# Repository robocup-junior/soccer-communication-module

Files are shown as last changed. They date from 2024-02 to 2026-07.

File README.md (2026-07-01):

# RCJ Soccer Communication Module

<p align="center">
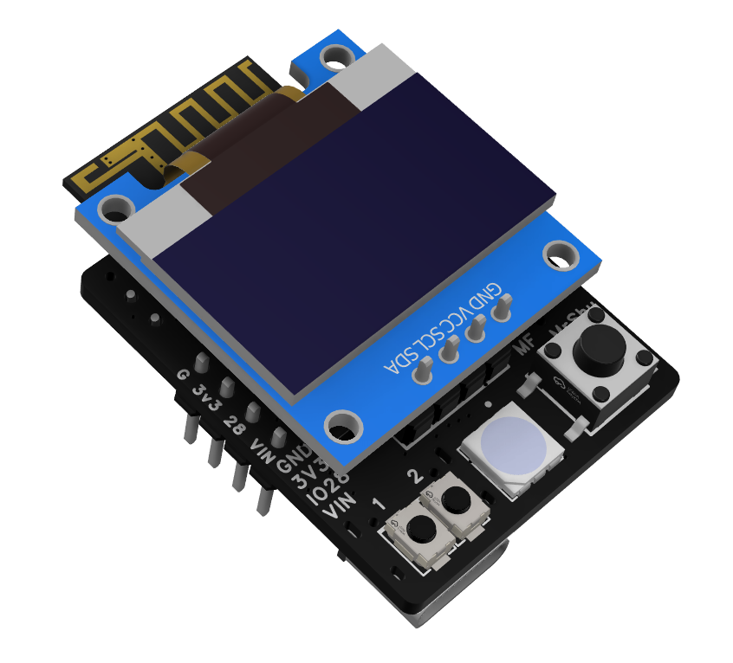
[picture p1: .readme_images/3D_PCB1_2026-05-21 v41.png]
RCJ Soccer communication module
  
</p>

A small referee-to-robot interface for **RoboCupJunior Soccer**. A referee controls the module over **Bluetooth Low Energy (BLE)** from the mobile app, and the module relays the live match state — **PLAY, STOP, penalty, half-time, game over** — to the robot or host controller over simple digital outputs, UART, or USB serial.

The current module (board **V7 / 2026**) is built around an **ESP32-C5** and includes an OLED display, three buttons, an RGB LED, a buzzer, a USB-C port for power & flashing, and an on-board **supercapacitor** backup. It does **not** count toward the robot weight limit.

> 📦 **Got an older 2024 board?** That one uses an ESP32-**C6** — see [Legacy 2024 (ESP32-C6) modules](#-legacy-2024-esp32-c6-modules) below.

---

## 🚀 Get started

**1. Install the referee app** — Android, free on Google Play:

**➡️ [RCJ Soccer app on Google Play](https://play.google.com/store/apps/details?id=com.robocup.rcj_soccer)**

**2. Flash the module** — easiest is the **web flasher**, nothing to install:

**➡️ [Web flasher](https://robocup-junior.github.io/soccer-communication-module/)** — connect the module over USB-C and flash straight from your browser.

> The web flasher uses the Web Serial API, so use **desktop Chrome or Edge**.

**3. Wire it to your robot** — power the module from the robot battery and read one start/stop signal (see [below](#-connecting-it-to-your-robot)).

---

## 📱 Using the app

The app connects to the module over BLE and drives the whole match. The interaction pattern:

- **Double-click** for actions — e.g. double-click a robot to start/stop it, or to issue a penalty.
- **Hold** for settings — e.g. hold a robot button for connection settings.
- **Start/stop** resets all timers and starts/stops all robots at once.
- **Score:** double-click a score to add a point; hold the score number for −1.

The app's source code lives in its own repository: **[robocup-junior/soccer-referee-app](https://github.com/robocup-junior/soccer-referee-app)**.

---

## 🔌 Connecting it to your robot

### Read the start/stop signal (pick one method)

The robot must respond to the start/stop signal for the entire game. Use **one** of the following methods and react whenever the state changes:

| Method | Pin | PLAY / GO | STOP |
|---|---|---|---|
| **Output pin** | `OUT1` or `OUT2` | **3.3 V** (HIGH) | **0 V** (LOW) |
| **UART** | `TX0` (UART0 on the U3 header) | sends `PLAY` | sends `STOP` |
| **USB serial** | USB-C | sends `PLAY` | sends `STOP` |

Both outputs carry the same 3.3 V logic-level signal. For 5 V robot inputs, add a level shifter before the robot. Always share **GND** with the robot controller — never connect VIN to a robot GPIO or to the 3.3 V pin.

For a Raspberry Pi or another USB host, connect the module's USB-C port to the host's USB-A port. The ESP32-C5 enumerates as a serial device, typically `/dev/ttyACM0`, and prints one line (`PLAY` or `STOP`) whenever the referee app changes the match state.

On Linux, you can check the USB serial output with:

```sh
stty -F /dev/ttyACM0 115200 raw -echo
cat /dev/ttyACM0
```

### Power it

Power the module **directly from the robot battery** so it stays alive for the whole match — even when the robot is switched off or removed from the field — to keep a stable BLE connection.

- **Battery:** connect **VIN** to battery **+** and **GND** to battery **−** (no switch in between). VIN accepts **4.5 V – 50 V** (the on-board buck regulator is rated higher, but RoboCupJunior rules cap robot voltage at 50 V).
- **USB-C:** the module can also run from USB-C (VBUS).
- **Regulated 3.3 V:** you may instead feed **3.3 V** to the 3V3 pin. If you do, design the supply to cover a short **startup demand of ~0.5 A at 3.3 V (≈1.65 W)**; steady-state draw is far lower.

### Supercapacitor backup

The back-side **supercapacitor** rides through short voltage dips during play (e.g. a battery sag). Switch the **supercapacitor switch ON before the match**, and **OFF when the module is not in use** so it doesn't stay charged in storage.

### Mounting

Mount the module where the **display stays visible** and the connector is **easy to reach** — typically on top of the robot via a hub, either on your own PCB or on protoboard/breadboard. We can also provide a limited number of **hub boards** you can permanently attach to your robot ([hub photo](./.readme_images/hub_image.png?raw=true)).

---

## ⏱️ During the match

### Penalties (fast & quiet)

To penalize a robot, **double-press the large button** on the module. The module sends a penalty request to the referee app, so the right robot is identified and the penalty timer starts — no shouting robot designators across the field. The firmware detects the double-press and sends the request **only while the robot is in the PLAY state**.

### Putting robots back in

The OLED shows a **countdown** for the duration of a robot's penalty. Teams may return robots to play, per the rules, once the penalty time is up on the display.

---

## 🤖 Robot-to-robot communication

Direct robot-to-robot communication is **planned for a future firmware release**. The current firmware relays the referee's match state (start/stop, penalty, half-time, game over) only — via the output pins or UART described above.

> The old 2024 board's channel-select `A0`/`A1` pins and the `LOGV` UART-level pin are **not** present on this hardware.

---

## 🛠️ Firmware & flashing (details)

For most users the [web flasher](https://robocup-junior.github.io/soccer-communication-module/) is all you need. Under the hood:

The firmware is an **ESP-IDF** project (Arduino runs as an IDF component). Releases are built automatically from Git tags matching `fw-*` or `v*` — pushing a tag makes GitHub Actions build the ESP32-C5 firmware, publish a GitHub Release with the `.bin` files, and deploy the latest web flasher to GitHub Pages:

```sh
git tag fw-v0.97
git push origin fw-v0.97
```

The release includes a single **merged image** (bootloader + partition table + app) plus the individual bins for `idf.py`/esptool users.

---

## 🧩 Legacy 2024 (ESP32-C6) modules

The older 2024 board uses an **ESP32-C6** (no USB-C connector) instead of the current ESP32-C5. It is still supported with a final, maintained firmware on the **[`legacy/esp32-c6`](https://github.com/robocup-junior/soccer-communication-module/tree/legacy/esp32-c6)** branch. Those builds are published as **GitHub Release assets** (tags `legacy-c6-*`); there is no web flasher for them.

**Flashing (native USB — recommended):** the C6's USB D+/D− are broken out on the programming header. Wire them to a USB port (the module enumerates as a serial device), then flash the merged image with full erase:

```sh
esptool --chip esp32c6 -p <PORT> write_flash --erase-all 0x0 rcj_comm_module-<ver>-merged.bin
```

A UART path also exists via the level-shifted RX/TX header pins, but it needs the `LOGV` pin powered at 3.3 V and manual download-mode entry (hold IO9/BOOT low, pulse EN), so native USB is easier. Either path can use the special flashing jig PCB.

---

## ❓ Not working?

Check the [open issues](https://github.com/robocup-junior/soccer-communication-module/issues) first and — if nobody has posted yours yet — open a [new GitHub issue](https://github.com/robocup-junior/soccer-communication-module/issues/new), post on [the forum](https://junior.forum.robocup.org/c/robocupjunior-soccer/5), or ask on the [RoboCupJunior Discord](https://discord.gg/45pxMQY4nJ).

## 🙌 Could use some help with

- An adapter hub for EV3 / SPIKE
- More component libraries (footprint / schematic / 3D) for Altium, Eagle, KiCad, EasyEDA, OrcaCAD, …
- Reporting errors & testing

## 🔭 Currently working on

- Robot-to-robot communication
- RGB LED & buzzer feedback

## 🏆 Hall of fame

- App by Mato Faltus
- Altium lib by Youssef Shaalan

---

## 📄 Quick connection guide

A printable one-page (A5) summary of the pinout, signals, power, and wiring:

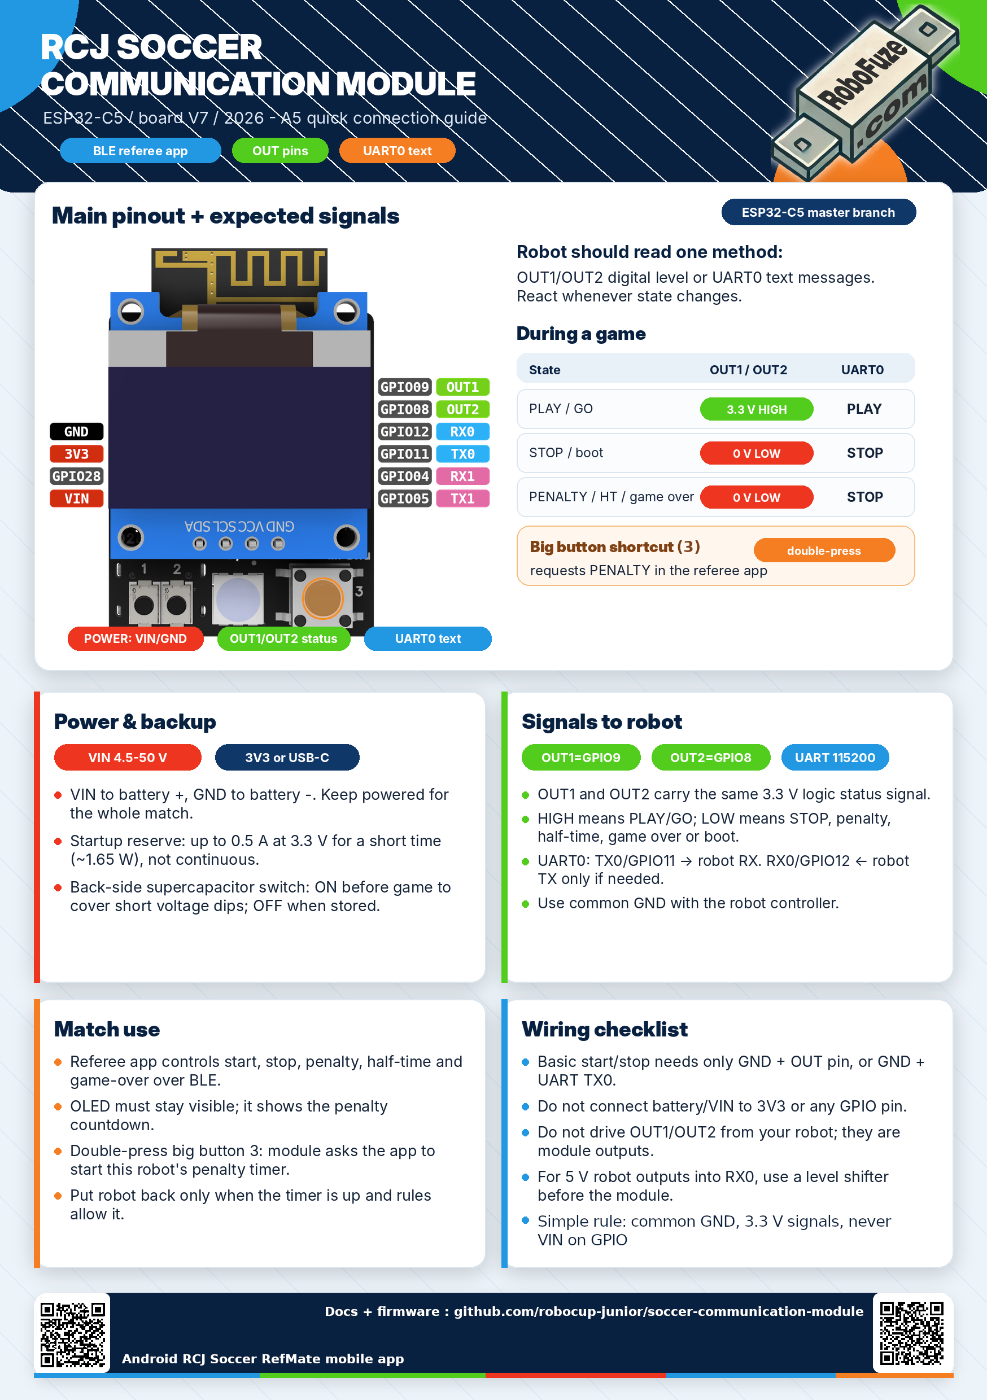
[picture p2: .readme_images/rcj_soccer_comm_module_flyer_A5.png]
RCJ Soccer Communication Module — quick connection guide


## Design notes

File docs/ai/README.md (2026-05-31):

# AI Agent Documentation — RCJ Soccer Communication Module

This folder is the **entry point for AI agents** (and humans) who need to understand
and later safely modify this project. It was written by inspecting the working tree,
source code, git history, build/release tooling, the web flasher, and the new-hardware
3D render images. Where something could not be proven from the repository it is marked
as **inferred**, **unknown**, or **to verify from schematic**.

> ℹ️ The public top-level `README.md` was rewritten on 2026-05-31 to describe the **current
> V7/2026 (ESP32-C5)** hardware (USB-C, RGB LED, buzzer, 3 buttons, supercap; no more
> A0/A1/LOGV pins). The old `RCJ 2024 communication modules.pdf` and 2024 design files were
> removed from `master` (they remain in git history / on `legacy/esp32-c6`). This `docs/ai/`
> folder and the live source code remain the most detailed source of truth.

> 📌 **Also read [`firmware/RCj_comm_module/AI_HANDOFF.md`](../../firmware/RCj_comm_module/AI_HANDOFF.md).**
> It is the handoff note written by the previous single-agent session that did the BLE
> latency, release-workflow, and web-flasher work. It has been cross-checked against the
> code and is **accurate and consistent with this docs set**; it adds the *rationale*
> behind several decisions (the since-revised 20 s BLE timeout, MAC-in-name for iPhones, NOTIFY
> over INDICATE, the manual USB RTS reset) and the **mobile-app expectations**. Key user
> rule from it: **never `git push` unless the user explicitly asks in that turn.**

## Project summary

A small board that mounts on a RoboCupJunior Soccer robot. It connects over **BLE** to a
mobile referee/control app (Nordic UART Service profile). The app sends match commands
(`PLAY`, `STOP`, penalty/damage, halftime, game over, score, name). The firmware drives
two digital **output pins** (`OUT1`/`OUT2`) that the robot reads to start/stop, and shows
the current match state on a 128×64 **SSD1306 OLED** (including a QR code of the BLE MAC
while waiting for a connection).

## Current status (as of fw v0.97)

- Firmware version **0.97** (`definitions.h`: `FW_VERSION_MAJOR=0`, `FW_VERSION_MINOR=97`),
  not yet tagged/released (latest released tag is `fw-v0.96`). v0.97 (working tree) bundles:
  `BLE_CONN_TIMEOUT` 20 s → 3 s (faster reconnect + faster fail-safe stop), and a clean
  release UART (bootloader/IDF logs OFF, console on UART0) with a `sdkconfig.debug` overlay
  for USB-C logging during development.
- Target chip: **ESP32-C5**, ESP-IDF **v5.5.4**, `espressif/arduino-esp32` `^3.3.0`, **NimBLE**.
- Runs on the new ESP32-C5 hardware in **legacy-compatibility mode**: same behavior as the
  old module, only with remapped pins. UART/`Serial` is still used (debug prints + legacy).
- New hardware (silkscreen **"V7 2026"**, branding "robofuze") adds RGB LED, buzzer,
  supercapacitor backup, three buttons, ON/OFF switch, and USB-C direct programming.
  **None of the RGB LED / buzzer / 3rd-button / supercap features are implemented in
  firmware yet.**
- Release/flashing is automated: Git tag → GitHub Actions → GitHub Release + GitHub Pages
  web flasher (Web Serial / esptool-js, ESP32-C5 USB reset path).

## Where to start reading

| Order | Document | Topic |
|---|---|---|
| 1 | [00_project_overview.md](00_project_overview.md) | What the module does, old vs new HW |
| 2 | [01_repository_map.md](01_repository_map.md) | Folder/file layout, source vs generated |
| 3 | [02_firmware_architecture.md](02_firmware_architecture.md) | Modules, main loop, RTOS queue |
| 4 | [03_ble_protocol.md](03_ble_protocol.md) | UUIDs, message IDs, payloads, direction |
| 5 | [04_state_machine.md](04_state_machine.md) | States, transitions, output behavior |
| 6 | [05_hardware_mapping.md](05_hardware_mapping.md) | Pin map (C5 + legacy C6), to-verify |
| 7 | [06_display_and_user_feedback.md](06_display_and_user_feedback.md) | Screens, proposed LED/buzzer |
| 8 | [07_build_release_and_flasher.md](07_build_release_and_flasher.md) | Build, CI, web flasher |
| 9 | [08_mobile_app_interaction.md](08_mobile_app_interaction.md) | App behavior, command mapping |
| 10 | [09_known_issues_and_open_questions.md](09_known_issues_and_open_questions.md) | Risks, TODOs, unknowns |
| 11 | [10_future_change_plan.md](10_future_change_plan.md) | Staged plan for new HW features |
| 12 | [11_legacy_c6_firmware.md](11_legacy_c6_firmware.md) | Final legacy ESP32-C6 firmware: git layout, build, flashing, release plan |

## Most important source files

| File | Role |
|---|---|
| `firmware/RCj_comm_module/RCj_comm_module.ino` | Arduino-IDE entry point (`setup`/`loop`) |
| `firmware/RCj_comm_module/main/app_main.cpp` | ESP-IDF entry point (`app_main`), mirrors the `.ino` |
| `firmware/RCj_comm_module/definitions.h` | Versions, BLE/UART constants, **GPIO pin map** |
| `firmware/RCj_comm_module/ble.cpp` / `.h` | BLE server, UUIDs, RX/TX characteristics, callbacks |
| `firmware/RCj_comm_module/ble_processing.cpp` / `.h` | Message IDs enum, queue, command dispatch |
| `firmware/RCj_comm_module/state_machine.cpp` / `.h` | States, output pin control, timers |
| `firmware/RCj_comm_module/display.cpp` / `.h` | OLED screen rendering |
| `firmware/RCj_comm_module/functions.cpp` / `.h` | MAC, score/indicator state, GPIO init, button logic |
| `tools/prepare_firmware_release.py` | Builds release artifacts + flasher manifest |
| `.github/workflows/firmware-release.yml` | CI build/release/Pages deploy |
| `web/flasher/app.js` | Web Serial flasher logic |

## Current limitations / cautions for agents

- **Do not make functional firmware changes** until the new schematic is available and the
  pin map in `05_hardware_mapping.md` is verified.
- The `.ino` and `main/app_main.cpp` define **two parallel entry points** that must be kept
  in sync (see [02](02_firmware_architecture.md)). The CI build uses the ESP-IDF path
  (`main/`), not the `.ino`.
- `BUTTON_GPIO` is shared between the disconnect (long-press) and penalty (double-press)
  logic — changing one affects the other.
- `stm_init()` sets a timer to `660000 ms` with a `// DOTO why ist here this? WTF` comment —
  origin/purpose unconfirmed (see [04](04_state_machine.md)).
- The **V7/2026 schematic is in the repo**: `pcb_schematic/SCH_Schematic1_2026-05-31.pdf`,
  with a pin-by-pin reference at `docs/ai/ESP32C5_RCJ_modul_hardware_reference.md`
  (**authoritative hardware source**). The firmware pin map matches it for all implemented
  peripherals. The older 2024 (C6) schematic/libraries were removed from `master` on
  2026-05-31 — find them in git history or on the `legacy/esp32-c6` branch.
</content>
</invoke>

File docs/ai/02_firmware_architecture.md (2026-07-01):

# 02 — Firmware Architecture

## Module breakdown

| Module | Files | Responsibility |
|---|---|---|
| Entry point (Arduino) | `RCj_comm_module.ino` | `setup()` / `loop()` for Arduino-IDE builds |
| Entry point (ESP-IDF) | `main/app_main.cpp` | `app_main()` → `initArduino()` + setup/loop, for CI/IDF builds |
| Definitions | `definitions.h` | Versions, BLE/UART constants, GPIO pin map |
| BLE transport | `ble.cpp` / `ble.h` | NimBLE server, NUS UUIDs, RX/TX characteristics, callbacks, send/disconnect |
| BLE processing | `ble_processing.cpp` / `ble_processing.h` | `ble_msg_t`, `ble_msg_id` enum, RTOS queue, command dispatch |
| State machine | `state_machine.cpp` / `state_machine.h` | `stm_states`, output-pin control, timer |
| Display | `display.cpp` / `display.h` | SSD1306 rendering per state |
| Functions/util | `functions.cpp` / `functions.h` | MAC string, score/indicator globals, GPIO init, button handling |
| Assets | `fonts.h`, `images.h` | OLED fonts and boot logo (`RC_logo`) |

## Two parallel entry points (IMPORTANT)

There are **two** entry points that do the same four things in the same order:

`RCj_comm_module.ino` (Arduino IDE):
```c
void setup() { Serial.begin(UART_SPEED); display_init(); module_init_gpios(); stm_init(); ble_start_server(); }
void loop()  { ble_msg_processing(); stm_update(); check_disconnect_button(); check_penalty_button(); }
```

`main/app_main.cpp` (ESP-IDF — what CI actually builds):
```c
static void module_setup() { Serial.begin(UART_SPEED); display_init(); module_init_gpios(); stm_init(); ble_start_server(); }
static void module_loop()  { ble_msg_processing(); stm_update(); check_disconnect_button(); check_penalty_button(); }
extern "C" void app_main(void) { initArduino(); module_setup(); while (true) { module_loop(); delay(1); } }
```

> **Maintenance hazard:** any change to setup/loop logic must be mirrored in **both** files,
> or the Arduino-IDE and ESP-IDF builds will diverge. The release pipeline builds the
> **ESP-IDF** path (`main/app_main.cpp`); the `.ino` is for local Arduino-IDE use.

## Initialization sequence

1. `Serial.begin(UART_SPEED)` — `UART_SPEED = 115200`. Used for debug prints only.
2. `display_init()` — `SSD1306 display(0x3c, I2C_SDA_GPIO, I2C_SCL_GPIO)`, `display.init()`.
3. `module_init_gpios()` — `OUTPUT1_GPIO`/`OUTPUT2_GPIO` as `OUTPUT`; `BUTTON_GPIO`/`BUTTON2_GPIO` as `INPUT` (no explicit pull configured — see hardware doc).
4. `stm_init()` — current state stays `STM_INIT`; sets timer to `660000 ms` (see below / [04](04_state_machine.md)).
5. `ble_start_server()` — creates the message queue, BLE device, server, service, RX/TX characteristics, and starts advertising.

## Main loop behavior

`loop()` runs continuously (in IDF: `while(true) { ...; delay(1); }`). Each iteration:

1. **`ble_msg_processing()`** — pops at most **one** message from the queue (`xQueueReceive`
   with timeout `0`) and dispatches it. Non-blocking; returns immediately if empty.
2. **`stm_update()`** — runs the current state's handler and, on a state change, updates
   the output pins.
3. **`check_disconnect_button()`** — long-press (`DISCONNECT_HOLD_TIME = 5000 ms`) on
   `BUTTON_GPIO` triggers `ble_disconnect()`.
4. **`check_penalty_button()`** — double-press on `BUTTON_GPIO` **or** `BUTTON2_GPIO`
   triggers `ble_msg_procesing_ask_for_penalty()`.

There is **no explicit task split**: everything runs in the single `app_main`/loop thread.
BLE callbacks run in the NimBLE host context and only enqueue work, keeping the ISR/callback
path short.

## Concurrency / FreeRTOS

The only cross-context shared structure is the BLE message queue.

- Created in `ble_msg_processing_init()`:
  `xQueueCreate(BLE_QUEUE_MAX_SIZE /*16*/, sizeof(ble_msg_t))`.
- **Producer:** `ble.cpp` `MyCallbacks::onWrite()` → `queue_ble_msg()` (BLE host context).
- **Consumer:** `ble_processing.cpp` `ble_msg_processing()` (main loop).

`queue_ble_msg()` (added in `ca23261`) implements an **overwrite-on-full** policy: if the
queue is full it drops the **oldest** message (`xQueueReceive`) and retries the send, so the
newest referee command is never lost to a backlog. Both `ble.cpp` and `ble_processing.cpp`
hold their own `static QueueHandle_t ble_msg_queue`; `ble.cpp` fetches the handle via
`ble_msg_proccesing_get_queue()` during `ble_start_server()`.

Other shared globals (`current_state`, `robot_play`, `timer_stop`, `module_indicator`,
`my_score`, `opponent_score`, `device_connected`) are accessed without locks. In practice
state mutations happen either in the loop or in BLE callbacks; `stm_set_state()` is called
from both `ble_processing` (loop) and `MyServerCallbacks::onDisconnect` (BLE context) —
a benign data race on `current_state`/`state_changed` that has not caused observed issues
but is worth noting for any future hardening.

## Important global state

| Variable | File | Meaning |
|---|---|---|
| `current_state` | `state_machine.cpp` | Active `stm_states` value |
| `state_changed` | `state_machine.cpp` | One-shot flag: forces re-render + output update next `stm_update()` |
| `robot_play` | `state_machine.cpp` | Drives `OUTPUT1/2` HIGH/LOW |
| `timer_stop` | `state_machine.cpp` | `millis()` deadline for penalty/halftime countdown |
| `device_connected` | `ble.cpp` | BLE connection state |
| `module_indicator` | `functions.cpp` | 2-char team/robot label (default `"--"`) |
| `my_score`, `opponent_score` | `functions.cpp` | Scoreboard values |

## Legacy UART / Serial behavior

- `Serial.begin(115200)` is called at startup.
- `update_output_satet()` in `state_machine.cpp` prints `"PLAY"` / `"STOP"` through
  `serial_status_println()` on every output change. That helper mirrors each line to
  Arduino `Serial` (UART0 on U3) and the ESP32-C5 USB Serial/JTAG port (USB-C, typically
  `/dev/ttyACM*` on Linux). **These are the only active serial status prints in the firmware**
  and double as status channels for robots or Raspberry Pi hosts that read serial instead
  of the OUT pins.
- All other debug prints are **already commented out**: `ble.cpp:45,64,147,149`,
  `ble_processing.cpp:71`, `functions.cpp:107,121`. (Verified 2026-05-31.) The vendored
  `libraries/**/examples/*.ino` prints are not compiled; the OLED lib's `"[deprecated]"`
  prints live in `drawLogBuffer()`/`setLogBuffer()`, which the firmware never calls.
- **No robot-to-robot UART protocol** (RX/TX framing, channel select) exists in the current
  firmware, despite the public README describing RX/TX/LOGV/A0/A1 on the 2024 board.

### UART output cleanliness (for robots that read serial, not pins)

Verified against the generated build config (`build/config/sdkconfig.h`, 2026-05-31):

1. **✅ `Serial` routes to UART0 (the U3 `TX_OUT` the robot reads).** `ARDUINO_USB_CDC_ON_BOOT`
   is **not** defined, so `Serial` = `HardwareSerial(0)` = UART0; and `CONFIG_ESP_CONSOLE_UART_DEFAULT=y`
   with `CONFIG_ESP_CONSOLE_UART_NUM=0`. So `PLAY`/`STOP` do reach the robot's UART pins.
   (`ARDUHAL` log level is already ERROR-only, so the Arduino layer adds no chatter.)
2. **✅ Boot log silenced for release (fixed 2026-05-31).** `sdkconfig.defaults` now sets
   `CONFIG_BOOTLOADER_LOG_LEVEL_NONE=y`, `CONFIG_LOG_DEFAULT_LEVEL_NONE=y`,
   `CONFIG_ARDUHAL_LOG_DEFAULT_LEVEL_NONE=y`, and pins the console to UART
   (`CONFIG_ESP_CONSOLE_UART_DEFAULT=y`). So a release build's UART0 line carries only the
   Arduino `Serial` output (`PLAY`/`STOP`) — those are plain UART writes, not log macros, so
   they survive. The ROM's very first line (`ESP-ROM:…`, reset cause) is emitted before
   sdkconfig applies and can only be removed via eFuse — **accepted as-is for now**
   (maintainer decision 2026-05-31): it's one short burst once at power-on, not during play.

### Build flavors: release (UART, clean) vs debug (USB, verbose)

| | Release (default) | Debug overlay |
|---|---|---|
| Config | `sdkconfig.defaults` only | `sdkconfig.defaults` + `sdkconfig.debug` |
| IDF/bootloader logs | OFF (`*_LOG_LEVEL_NONE`) | INFO |
| IDF console route | UART0 | **USB-C** (`CONFIG_ESP_CONSOLE_USB_SERIAL_JTAG`) |
| Arduino `Serial` (`PLAY`/`STOP`) | UART0; mirrored to USB-C by `serial_status` | UART0; mirrored to USB-C by `serial_status` |
| Built by | CI on every tag | local dev only |

Debug build command:
`idf.py -D SDKCONFIG_DEFAULTS="sdkconfig.defaults;sdkconfig.debug" build flash monitor`
(later defaults file wins on conflicting choices). This keeps the UART0 line free for the
robot while a developer watches logs over USB-C. `Serial`'s `PLAY`/`STOP` stays on UART0 in
both flavors, and `serial_status` mirrors those same lines to USB Serial/JTAG for USB hosts.

## Source files reviewed

`RCj_comm_module.ino`, `main/app_main.cpp`, `definitions.h`, `ble.cpp/.h`,
`ble_processing.cpp/.h`, `state_machine.cpp/.h`, `display.cpp/.h`, `functions.cpp/.h`,
git commit `ca23261`.

## Open questions

- Should the loop adopt a dedicated FreeRTOS task / explicit synchronization for state?
- Is the `.ino` still maintained, or should it be retired in favor of the IDF `main/` path?
</content>

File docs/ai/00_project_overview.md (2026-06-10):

# 00 — Project Overview

## What this module is

The RCJ Soccer Communication Module is a small mountable board for RoboCupJunior Soccer
robots. It provides a referee-controlled start/stop (and penalty/halftime/game-over)
channel between a mobile referee app and the robot, plus a status display. The board does
not count toward the robot weight limit (per public `README.md`).

Core responsibilities:

1. Advertise and accept a **BLE** connection from the mobile referee/control app.
2. Receive match commands over BLE and react.
3. Drive two digital **output pins** (`OUT1`, `OUT2`) that the robot continuously reads:
   **3.3 V = GO/PLAY, 0 V = STOP** (public README confirms the electrical meaning).
4. Show the current state on a 128×64 OLED, including a QR code of the BLE MAC address
   while waiting for a connection, and a penalty/halftime countdown.
5. Offer local buttons for disconnect and a self-penalty request back to the app.

## Match-level behavior

| Phase | What happens |
|---|---|
| Power-on | Boot/logo screen with firmware version, then "Wait for connection" screen with QR + MAC |
| Referee connects (app) | BLE link established; app drives state |
| `PLAY` | Outputs go HIGH; robot plays; display shows team indicator + score |
| `STOP` | Outputs go LOW; robot stops |
| Penalty / damage | Outputs LOW; display shows a countdown; robot returns when timer hits 0 |
| Halftime | Outputs LOW; display shows a countdown |
| Game over | Outputs LOW; display shows final score + indicator |
| Self-penalty request | Local double-press of the button asks the app for a penalty (only while playing) |
| BLE disconnect | Returns to "Wait for connection" state |

The module is expected to be **powered at all times during the match** (even off-field) to
keep the BLE link stable (public README). The new hardware adds a **supercapacitor** so the
module can survive a short power drop without losing the connection/state (maintainer note).

## Control flow: app → BLE → module → robot

```
Mobile referee app
      │  BLE write (Nordic UART RX characteristic)
      ▼
ble.cpp  MyCallbacks::onWrite()  ── parses [msg_id][data...] ──► FreeRTOS queue
      │
      ▼
ble_processing.cpp  ble_msg_processing()  ── dispatch by msg_id ──►
      ├─ stm_set_state(STM_PLAY/STOP/DAMAGE/HALF_TIME/GAME_OVER)
      ├─ module_set_indicator() / module_set_my_score() / module_set_opponent_score()
      └─ ble_send_msg() for PING echo / FW_VERSION reply
      │
      ▼
state_machine.cpp  stm_update()
      ├─ update_output_satet(): OUTPUT1/OUTPUT2 GPIO HIGH (play) or LOW (stop)
      └─ display_screen_*(): render current screen
      │
      ▼
Robot reads OUT1/OUT2 (3.3 V = GO, 0 V = STOP)
```

The reverse direction (module → app) carries: `BLE_MSG_PING` echo, `BLE_MSG_FW_VERSION`
reply, `BLE_MSG_ASK_FOR_PENALTY` (self-penalty request), and `BLE_MSG_DISCONNECT`
notification before disconnecting. See [03_ble_protocol.md](03_ble_protocol.md).

## Old hardware vs new ESP32-C5 hardware

| Aspect | Old 2024 module | New module (silkscreen "V7 2026", "robofuze") |
|---|---|---|
| MCU | ESP32-**C6** (legacy pin block still commented in `definitions.h`) | ESP32-**C5** (PCB-antenna module) |
| Programming | External (per old docs) | **USB-C** direct, onboard |
| Power | BAT+ / GND (5.3–25 V) or 3V3 | Same + **supercapacitor backup**, ON/OFF slide switch |
| Inputs | Buttons (2 used in firmware) | **3 buttons** (silk "1", "2", "3"/"MF") |
| Feedback | OLED display | OLED + **RGB LED** + **buzzer** |
| Robot I/O | RX/TX UART, A0/A1 channels, LOGV, OUT1/OUT2 | OUT1/OUT2 confirmed in firmware; UART/RX-TX status **to verify** |

> The old/UART-based robot-to-robot communication (RX, TX, LOGV, A0/A1 channels) is
> described only in the public README/PDF. The **current firmware does not implement any
> RX/TX robot-to-robot UART protocol** — `Serial` is used at 115200 baud only for debug
> prints (`"PLAY"`/`"STOP"`) and as a side effect of `Serial.begin()`. The V7 schematic
> shows the board keeps UART headers — UART0 (RX0/TX0, primary/flashing) and UART1
> (RX1=IO4, TX1=IO5, secondary to robot) on the U3 connector — but the legacy LOGV/A0/A1
> channel scheme is gone. See [05_hardware_mapping.md](05_hardware_mapping.md).

## Current compatibility mode

The maintainer describes the firmware as running on ESP32-C5 in a **limited compatibility
mode**: it behaves like the old hardware with changed pins. Concretely, the only behavioral
delta vs the old code path that is implemented is:

- Pin remap to ESP32-C5 (`definitions.h`, C6 block commented out).
- BLE switched to NimBLE with tuned connection parameters and write-without-response
  (commit `ca23261` "Improve BLE command latency and resilience").
- A self-penalty request via double-press (commit `e423b0d`).

## Planned hardware features (NOT implemented yet)

These are on the board (confirmed in the V7 schematic) but have **no firmware support yet**;
pins are now known (see [05_hardware_mapping.md](05_hardware_mapping.md)):

- **RGB LED** — discrete common-cathode, active-high: R=IO27, G=IO24, B=IO23 (470 Ω each).
  ⚠️ **R/G are swapped on the real board** (footprint bug): IO27 lights **green**, IO24
  lights **red** (blue is fine). See [05](05_hardware_mapping.md) / the hardware reference.
- **Buzzer** — passive 2.7 kHz via NPN Q1 on **IO26** (pin 27); needs PWM tone.
- **Supercapacitor backup** — 15 F (C1); hardware ride-through, no firmware action required.
- **Third button** B3 = **IO6** (SW2) — firmware currently wires only two buttons
  (`BUTTON_GPIO`=IO10/B1, `BUTTON2_GPIO`=IO7/B2).
- **Slide power switch** (U6) — enables/disables supercap backup; firmware-invisible.

Do not implement these until the schematic confirms pins. See
[10_future_change_plan.md](10_future_change_plan.md).

## Source files reviewed

`README.md`, `firmware/RCj_comm_module/*` (all `.ino/.cpp/.h`), `main/app_main.cpp`,
`.readme_images/3D_PCB1_2026-05-21 v4*.png`, git history (`7f9fb81`, `ca23261`, `e423b0d`).

## Open questions

- Does the new board still expose a robot-to-robot UART (RX/TX/LOGV/A0/A1) header?
- Must old-module BLE compatibility be preserved bit-for-bit with the existing app?
- Is the supercapacitor purely hardware ride-through, or should firmware detect a power dip?
</content>

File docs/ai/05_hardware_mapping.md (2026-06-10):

# 05 — Hardware Mapping

The V7/2026 schematic is now in the repo and the pin map is **confirmed**:
- Schematic: `pcb_schematic/SCH_Schematic1_2026-05-31.pdf` (EasyEDA "ESP32C5_RCJ_modul",
  Board1 / Schematic1, V1.0, MCU **ESP32-C5-WROOM-1** — schematic label `-N16R4`, but the
  fitted flash reads **8 MB** via JEDEC (build is configured for 8 MB; see the hardware
  reference's "Microcontroller — U1" note) / 4 MB PSRAM).
- Authoritative pin reference (maintainer-authored, read pin-by-pin from U1):
  [`ESP32C5_RCJ_modul_hardware_reference.md`](ESP32C5_RCJ_modul_hardware_reference.md).

> ✅ **The firmware (`definitions.h`) matches the V7 hardware for every implemented
> peripheral** (I2C, the two wired buttons, the two robot outputs). The RGB LED, buzzer,
> third button, and UART1 exist on the board but are **not yet used by firmware** — their
> confirmed pins are listed below.

## Current firmware pin map — ESP32-C5 (active)

```c
// ESP-C5  (definitions.h)
#define I2C_SDA_GPIO    2     // OLED SDA
#define I2C_SCL_GPIO    3     // OLED SCL
#define BUTTON_GPIO     10    // primary button (disconnect long-press + penalty double-press)
#define BUTTON2_GPIO     7    // secondary button (penalty double-press)
#define OUTPUT1_GPIO     9    // robot start/stop OUT1 (HIGH=play, LOW=stop)
#define OUTPUT2_GPIO     8    // robot start/stop OUT2 (mirrors OUT1)
```

| Function | C5 GPIO | Direction | V7 net / part | Notes |
|---|---|---|---|---|
| I2C SDA (OLED) | 2 | — | SDA, H2 hdr | `SSD1306(0x3c, SDA, SCL)` ✅ matches HW |
| I2C SCL (OLED) | 3 | — | SCL, H2 hdr | I2C addr `0x3c` ✅ matches HW |
| OUT1 | 9 | output | OUT1, U3 hdr | robot GO/STOP signal ✅ matches HW (IO9) |
| OUT2 | 8 | output | OUT2, U3 hdr | duplicate of OUT1 ✅ matches HW (IO8) |
| BUTTON | 10 | input | **B1 = SW5** | disconnect (5 s hold) **and** penalty (double-press); SW5 is the 4-pin slide/toggle "power/mode" switch |
| BUTTON2 | 7 | input | **B2 = SW1** | penalty (double-press); SW1 momentary tactile |

> Note: firmware `BUTTON_GPIO` (10) is hardware **B1/SW5** (the 4-pin slide/toggle switch),
> and `BUTTON2_GPIO` (7) is **B2/SW1**. The third button **B3/SW2 = IO6** is not wired in
> firmware. Hardware provides 10 kΩ pull-ups (R4/R5/R6) on all three, so the buttons are
> active-low as the firmware assumes.

## Legacy pin map — ESP32-C6 (commented out, retained for reference)

```c
// ESP-C6  (commented in definitions.h)
// I2C_SDA_GPIO    6
// I2C_SCL_GPIO    7
// BUTTON_GPIO     18
// BUTTON2_GPIO     9
// OUTPUT1_GPIO    20
// OUTPUT2_GPIO    19
```

These are kept as comments from the previous (C6) hardware revision. They are **not**
compiled. Useful only if a C6 board must be reflashed.

## Display / I2C

- Driver: ThingPulse SSD1306 (`libraries/ESP8266_and_ESP32_OLED_driver_for_SSD1306_displays`).
- Instance: `static SSD1306 display(0x3c, I2C_SDA_GPIO, I2C_SCL_GPIO)` in `display.cpp`.
- Resolution assumed 128×64 (boot draws `drawXbm(0,0,128,64,RC_logo)`).
- The new board exposes a 4-pin OLED header silk-labeled **`GND VCC SCL SDA`** (visible in
  the front render) — consistent with an external/standard SSD1306 module.

## Button handling (current behavior)

`functions.cpp`:
- `module_init_gpios()` sets `BUTTON_GPIO` and `BUTTON2_GPIO` as `INPUT`
  (no `INPUT_PULLUP` in firmware — OK because the board has **external 10 kΩ pull-ups**
  R4/R5/R6 to 3.3 V; confirmed in the schematic).
- Buttons are **active-low**: pressed reads `LOW` (`digitalRead(...) == LOW`,
  and penalty logic uses `!digitalRead(...)`).
- **`check_disconnect_button()`**: holding `BUTTON_GPIO` LOW for `DISCONNECT_HOLD_TIME`
  (5000 ms) calls `ble_disconnect()`.
- **`check_penalty_button()`**: a debounced (`DEBOUNCE_DELAY` 50 ms) **double-press**
  (within `DOUBLE_PRESS_MAX_DELAY` 1000 ms) of `BUTTON_GPIO` **OR** `BUTTON2_GPIO` calls
  `ble_msg_procesing_ask_for_penalty()` (sends `BLE_MSG_ASK_FOR_PENALTY`, only while
  `STM_PLAY`).

> **Shared-pin caution:** `BUTTON_GPIO` participates in both the disconnect long-press and
> the penalty double-press logic. A long hold could also register press edges in the penalty
> detector. Keep this in mind when redefining button roles for the 3-button board.

## UART / serial

- `UART_SPEED = 115200`. `Serial.begin()` at boot; used for `"PLAY"`/`"STOP"` debug prints.
- The V7 board exposes **two UARTs** on the U3 6-pin header (2541WV-06P):
  - **UART0** — `RX0`/`TX0` (net `RX_OUT`/`TX_OUT`, U3 pins 3–4). Primary serial, also the
    flashing/boot console.
  - **UART1** — `RX1 = IO4`, `TX1 = IO5` (U3 pins 5–6). Secondary serial to the robot.
- The 2024 README's RX/TX/LOGV/A0/A1 "channel" scheme is **not** present; the V7 board has
  plain UART0/UART1 instead. Firmware does **not** use UART1 yet.

## New V7/2026 hardware — CONFIRMED from schematic (NOT yet in firmware)

Pins below are from `ESP32C5_RCJ_modul_hardware_reference.md` (read pin-by-pin from U1) and
`pcb_schematic/SCH_Schematic1_2026-05-31.pdf`. Components seen on the 3D renders
(`.readme_images/3D_PCB1_2026-05-21 v4*.png`, silk "V7 2026", branding "robofuze").

| Feature | GPIO / part | Active level / drive | Firmware status |
|---|---|---|---|
| RGB LED Red | **IO27** via R9 470 Ω — ⚠️ **lights GREEN** (R/G footprint swap) | active **high** | not implemented |
| RGB LED Green | **IO24** via R8 470 Ω — ⚠️ **lights RED** (R/G footprint swap) | active high | not implemented |
| RGB LED Blue | **IO23** via R7 470 Ω | active high | not implemented |
| RGB LED part | LED1 `TC5050RGBF08-3CJH-AF53A` | common-cathode, PWM-capable per channel; ⚠️ **R/G pads swapped vs schematic** (real part is G,R,B) | — |
| Buzzer | **IO26** (pin 27) → Q1 (BC817-40) base via R3 470 Ω | drive high; **passive 2.7 kHz** → use PWM ~2.7 kHz | not implemented |
| Third button **B3** | **IO6** = SW2 | active low, 10 kΩ pull-up (R4) | not wired |
| UART1 RX / TX | **IO4 / IO5** (U3 pins 5–6) | — | not used |
| GPIO28 | **IO28** on H1 header pin 2 | — | exposed to robot; could sense power if external ckt added |
| Supercapacitor | C1 **15 F**, charge via R14 15 Ω, D3 SS34 | hardware ride-through | no firmware action needed |
| Power switch | U6 `MSS12C02LS-BB2.0` slide switch | enables/disables supercap backup | hardware-only |
| Buck converter | U4 `LMR51610XDBVR`, L=22 µH | VIN → 3.3 V | hardware-only |
| USB-C | USB1, D-=IO13, D+=IO14 (33 Ω series), CC 5.1 kΩ (UFP) | native USB-CDC, flashing + power | flashing path |

## Residual items to verify (low risk; do not block firmware re-pinning)

1. **OLED pull-ups.** No I2C pull-ups on-board; the OLED module is assumed to provide them
   (matches current working behavior). Verify when selecting a display.
2. **RGB LED part description** says "common cathode" while channels are driven **active
   high through a series resistor to the GPIO** — consistent with common-cathode; confirm
   polarity on first bring-up.
3. ✅ **RGB Red/Green are SWAPPED (confirmed bug, 2026-06-02).** The LED1 footprint is wired
   R,G,B but the real `TC5050RGBF08` part is **G,R,B**, so **IO27 lights green and IO24
   lights red** (IO23/blue is fine). Firmware must drive IO24 for red and IO27 for green
   until the footprint is fixed in a future board revision. See
   [`ESP32C5_RCJ_modul_hardware_reference.md`](ESP32C5_RCJ_modul_hardware_reference.md) →
   "RGB LED — LED1".

> Buzzer GPIO confirmed by maintainer (2026-05-31): **IO26 (pin 27)** — no longer in doubt.

## Source files reviewed

`definitions.h`, `functions.cpp`, `display.cpp`,
`docs/ai/ESP32C5_RCJ_modul_hardware_reference.md`,
`pcb_schematic/SCH_Schematic1_2026-05-31.pdf`, the three V7 render PNGs.

## Open questions

- Intended firmware roles for B3 (IO6), the RGB LED, the buzzer, and UART1.
</content>

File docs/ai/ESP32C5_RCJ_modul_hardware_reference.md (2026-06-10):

# ESP32C5_RCJ_modul — Hardware Reference for AI Coding Agents

**Schematic:** Schematic1
**Board:** Board1
**Version:** V1.0
**Created:** 2025-12-10 | **Last updated:** 2026-02-21
**Tool:** EasyEDA

---

## Overview

This is a compact robot controller module built around the **ESP32-C5-WROOM-1** (the schematic symbol is labeled `-N16R4`, but the flash actually fitted reads **8 MB** via JEDEC ID — see the note under "Microcontroller — U1"). It is designed to be mounted on a robot via two pin headers and programmed over USB-C. The board includes onboard buttons, an RGB LED, a buzzer, an I2C expansion port for an OLED display, and a supercapacitor-backed power system with a soft power switch.

---

## Microcontroller — U1

| Parameter | Value |
|---|---|
| Part | ESP32-C5-WROOM-1 (schematic label `-N16R4`) |
| Architecture | RISC-V single-core, Wi-Fi 6, BLE 5 |
| Flash | **8 MB** (measured) — see note |
| PSRAM | 4 MB |
| Package | 38-pin module |

The module is the central processing unit. All peripherals connect to it through the GPIO assignments listed below.

> ⚠️ **Flash size: schematic says N16R4 (16 MB), but the physical chip reads 8 MB.**
> `esptool flash_id` on a real board (2026-05-31) reports manufacturer `0x20`, device
> `0x4017` → size byte `0x17` = 2²³ = **8 MB**, and the boot ROM auto-detects `8192k`. The
> firmware build is therefore configured for **8 MB** (`CONFIG_ESPTOOLPY_FLASHSIZE_8MB` in
> `firmware/RCj_comm_module/sdkconfig.defaults`). Treat 8 MB as ground truth; the `-N16R4`
> marking is either a BOM/labeling discrepancy or a different flash variant was stuffed.

---

## GPIO Pin Assignment

Read directly from the U1 (ESP32-C5-WROOM-1-N16R4) schematic symbol pin-by-pin.

| GPIO | Module Pin | Net Label | Function | Notes |
|---|---|---|---|---|
| IO2  | 4  | SDA | I2C SDA | OLED display data — H2 header |
| IO3  | 5  | SCL | I2C SCL | OLED display clock — H2 header |
| IO4  | 17 | RX1 | UART1 RX | Secondary serial from robot (U3 connector) |
| IO5  | 16 | TX1 | UART1 TX | Secondary serial to robot (U3 connector) |
| IO6  | 8  | B3 | Button B3 | SW2, pulled up to 3.3V via R4 10kΩ, active low |
| IO7  | 9  | B2 | Button B2 | SW1, pulled up to 3.3V via R5 10kΩ, active low |
| IO8  | 10 | OUT2 | Robot output 2 | U3 connector pin OUT2 |
| IO9  | 11 | OUT1 | Robot output 1 | U3 connector pin OUT1 |
| IO10 | 12 | B1 | Button B1 | SW5, pulled up to 3.3V via R6 10kΩ, active low |
| IO13 | 13 | GPIO13 | USB D- | USB1 via R10 33Ω |
| IO14 | 14 | GPIO14 | USB D+ | USB1 via R11 33Ω |
| IO23 | 20 | B | LED Blue | LED1 via R7 470Ω, active high |
| IO24 | 22 | G | LED Green ⚠️ *(lights **Red** — see LED1 note)* | LED1 via R8 470Ω, active high |
| IO26 | 27 | BUZZER | Buzzer driver | Q1 base via R3 470Ω, drive high to activate |
| IO27 | 18 | R | LED Red ⚠️ *(lights **Green** — see LED1 note)* | LED1 via R9 470Ω, active high |
| IO28 | 15 | GPIO28 | Robot GPIO | H1 header pin 2, exposed to robot connector |
| RX0  | 24 | RX_OUT | UART0 RX | U3 connector; primary serial / flashing |
| TX0  | 25 | TX_OUT | UART0 TX | U3 connector; primary serial / flashing |

> **Note:** NC/IO15 (pin 19), IO0 (pin 6), IO1 (pin 7) are not connected or reserved. Always verify against the EasyEDA netlist. (IO26 / pin 27 **is** used — it drives the buzzer.)

---

## Buttons

Three tactile push buttons, all using **TS-1088-AR02016** footprint. All are **active low** (pulled up to 3.3V).

| Designator | Net Label | GPIO | Description |
|---|---|---|---|
| SW5 | B1 | IO10 | Power/mode switch (TS-1002S-07026C, 4-pin) |
| SW1 | B2 | IO7  | General-purpose button |
| SW2 | B3 | IO6  | General-purpose button |

**Firmware note:** Configure all button pins as `INPUT` with internal or external pull-up. Debounce in software (recommended: 20–50 ms). SW5 is physically a 4-pin slide/toggle switch (TS-1002S-07026C), while SW1 and SW2 are standard momentary tactile buttons.

---

## RGB LED — LED1

> ⚠️ **Red/Green are SWAPPED on the real board — schematic footprint bug.**
> The `TC5050RGBF08-3CJH-AF53A` part's physical pin order is **G, R, B**, but the LED1
> footprint in the schematic is wired as **R, G, B**, so the Red and Green pads are
> reversed on the PCB. The labels below (and the "Schematic" column) reflect the
> *schematic*; the **As-built** column is what actually lights up. Confirmed on hardware
> **2026-06-02** by flashing firmware that drives play→green and seeing red instead.
> Blue is unaffected.

| Parameter | Value |
|---|---|
| Part | TC5050RGBF08-3CJH-AF53A |
| Type | Common cathode RGB LED |
| Current limiting | R7, R8, R9 — all 470Ω to 3.3V rail |

| GPIO  | Resistor | Schematic label | **As-built (real) color** |
|---|---|---|---|
| IO27  | R9 470Ω  | Red | 🟢 **Green** |
| IO24  | R8 470Ω  | Green | 🔴 **Red** |
| IO23  | R7 470Ω  | Blue | 🔵 Blue (correct) |

**Firmware note:** Each channel is driven independently; drive the GPIO high to turn the
color on, and PWM is supported on all three for brightness/mixing. **Because of the
footprint swap, firmware must drive IO24 to show red and IO27 to show green** (until the
footprint is corrected in a future board revision — the proper long-term fix).

---

## Buzzer — BUZZER1

| Parameter | Value |
|---|---|
| Part | Passive buzzer, 2.7 kHz resonant frequency |
| Driver | NPN transistor Q1 (BC817-40) |
| Base resistor | R3 470Ω |
| Flyback diode | D1 (1N4148W-7-F) |
| GPIO | IO26 |

**Firmware note:** Drive IO26 high to activate. For passive buzzers, generate a PWM signal at or near 2.7 kHz for maximum volume. The transistor sinks current through the buzzer; D1 protects against inductive spikes.

---

## I2C Interface — OLED Display

| Parameter | Value |
|---|---|
| Header | H2 (PZ254V-11-04P, 4-pin) |
| SDA | IO1 (pin 1 of H2) |
| SCL | IO2 (pin 2 of H2) |
| Power | 3.3V (pin 3 of H2) |
| GND | GND (pin 4 of H2) |

**Firmware note:** Standard I2C bus. Typical OLED displays (SSD1306, SH1106) operate at 3.3V and use address `0x3C` or `0x3D`. Use I2C clock speed up to 400 kHz (Fast Mode). No onboard pull-up resistors are visible on the schematic — the OLED module likely includes them, but verify when selecting a display.

---

## USB-C Connector — USB1

| Parameter | Value |
|---|---|
| Part | TYPE-C 16PIN 2MD(073) |
| D+ | GPIO14 via R11 33Ω |
| D- | GPIO13 via R10 33Ω |
| CC resistors | R12, R13 — both 5.1kΩ to GND (USB-C UFP / device mode) |
| Protection diode | D2 (1N5819HW-7-F) on VBUS line |

The USB-C port is used for:
- **Flashing firmware** via USB Serial (USB-CDC or UART boot)
- **Power input** (VBUS → VIN rail via D2)

The 5.1kΩ CC resistors configure the connector as a **UFP (device)**, so it is recognized as a standard USB device by host computers. No host/OTG mode.

---

## Power Supply System

### Input Path

```
USB-C VBUS ──D2──► VIN rail
                        │
                   U4 (LMR51610XDBVR) Buck converter
                        │
                      3.3V rail ──► all logic
```

### Buck Converter — U4

| Parameter | Value |
|---|---|
| Part | LMR51610XDBVR (Texas Instruments) |
| Topology | Synchronous step-down (buck) |
| Input | VIN (from USB-C or robot header) |
| Output | 3.3V |
| Inductor | U5 22µH |
| Input caps | C2 2.2µF, C3 2.2µF, C4 100nF |
| Output caps | C5 10µF, C6 10µF, C7 10µF |
| Feedback cap | C8 100nF |
| Feedback divider | R1 100kΩ (top), R2 32kΩ (bottom) |

The feedback divider sets the output voltage. Verify R1/R2 values against the LMR51610 datasheet if output voltage needs to be changed.

### Supercapacitor Backup — C1

| Parameter | Value |
|---|---|
| Part | C1 supercapacitor |
| Capacitance | 15F |
| Purpose | Hold power rail during brief supply interruptions |
| Charge path | Via R14 15Ω (current-limiting resistor) |
| Discharge protection | D3 (SS34 Schottky diode) |
| Switch | MSS12C02LS-BB2.0 (U6) — slide switch for enabling/disabling backup |

**Firmware note:** The supercapacitor provides ride-through during power dropout (e.g., when robot battery dips). No firmware action is required to benefit from it. GPIO28 is exposed on H1 and could be used to monitor power status if external circuitry is added.

---

## Robot Interface Connectors

### H1 — 4-pin Header (PZ254V-11-04P)

| Pin | Signal |
|-----|---|
| 1 | GND |
| 2 | GPIO28 |
| 3 | 3.3V |
| 4 | VIN |

Used to expose the raw input voltage and GPIO28 to the robot mainboard.

### U3 — 6-pin Header (2541WV-06P)

| Pin | Signal | Direction |
|-----|---|---|
| 1 | OUT1 | Output to robot |
| 2 | OUT2 | Output to robot |
| 3 | RX_OUT | UART0 TX (from ESP32 perspective: transmit out) |
| 4 | TX_OUT | UART0 RX (from ESP32 perspective: receive in) |
| 5 | RX1 | UART1 RX |
| 6 | TX1 | UART1 TX |

> **Important:** The net labels RX_OUT / TX_OUT reflect the signal direction **from the module's perspective**. When wiring to a robot MCU, cross RX↔TX as usual.

### H2 — 4-pin Header (PZ254V-11-04P)

Dedicated I2C header for OLED display (see I2C section above).

---

## Communication Interfaces Summary

| Interface | GPIOs | Connector | Usage |
|---|---|---|---|
| USB Serial (UART0) | IO13 (D-), IO14 (D+) | USB-C | Firmware flashing, debug console |
| UART0 | RX0 / TX0 | U3 pins 3–4 | Primary serial to robot |
| UART1 | RX1 / TX1 | U3 pins 5–6 | Secondary serial to robot |
| I2C | IO1 (SDA), IO2 (SCL) | H2 | OLED display |

---

## Component Reference Table

| Designator | Part | Value / Description |
|---|---|---|
| U1 | ESP32-C5-WROOM-1-N16R4 | Main MCU module |
| U4 | LMR51610XDBVR | Buck converter, 3.3V output |
| U5 | Inductor | 22µH, buck converter |
| U6 | MSS12C02LS-BB2.0 | Slide switch for supercap backup |
| USB1 | TYPE-C 16PIN 2MD(073) | USB-C connector |
| H1 | PZ254V-11-04P | 4-pin robot power/GPIO header |
| H2 | PZ254V-11-04P | 4-pin I2C display header |
| U3 | 2541WV-06P | 6-pin robot UART/IO header |
| LED1 | TC5050RGBF08-3CJH-AF53A | RGB LED |
| BUZZER1 | — | Passive buzzer, 2.7 kHz |
| Q1 | BC817-40 | NPN transistor, buzzer driver |
| SW1, SW2 | TS-1088-AR02016 | Tactile push buttons |
| SW5 | TS-1002S-07026C | 4-pin slide/toggle switch |
| C1 | — | 15F supercapacitor |
| D1 | 1N4148W-7-F | Flyback diode (buzzer) |
| D2 | 1N5819HW-7-F | VBUS protection diode |
| D3 | SS34 | Schottky diode, supercap discharge path |
| R1 | 100kΩ | Buck feedback top |
| R2 | 32kΩ | Buck feedback bottom |
| R3 | 470Ω | Buzzer transistor base |
| R4, R5, R6 | 10kΩ | Button pull-up resistors |
| R7, R8, R9 | 470Ω | RGB LED current limiting |
| R10, R11 | 33Ω | USB D+/D- series resistors |
| R12, R13 | 5.1kΩ | USB-C CC pull-down (UFP) |
| R14 | 15Ω | Supercap charge current limiter |
| C2, C3 | 2.2µF | Buck input capacitors |
| C4, C8 | 100nF | Decoupling |
| C5, C6, C7 | 10µF | Buck output capacitors |
| C9 | 10µF | ESP32 3.3V decoupling |

---

## Firmware Quick-Start Checklist

- [ ] Set IO27, IO24, IO23 as `OUTPUT` for R/G/B LED channels — ⚠️ **R/G swapped on the real board: IO27 lights green, IO24 lights red** (footprint bug, see "RGB LED — LED1")
- [ ] Set IO10, IO7, IO6 as `INPUT` (pull-up) for buttons B1/B2/B3 (active low)
- [ ] Set IO26 as `OUTPUT` for buzzer; use PWM at ~2700 Hz
- [ ] Initialize I2C on SDA=IO2, SCL=IO3 for OLED
- [ ] Set IO9, IO8 as `OUTPUT` for OUT1/OUT2 robot signals
- [ ] UART0 is the USB serial port (flashing + debug)
- [ ] UART1 (RX1/TX1) available for robot communication via U3 header
- [ ] GPIO28 exposed on H1 — available for robot-side signaling

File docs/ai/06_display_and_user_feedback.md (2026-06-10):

# 06 — Display and User Feedback

Rendering lives in `display.cpp` using the ThingPulse SSD1306 driver (128×64, I2C `0x3c`)
and the `QRcodeOled` library. Fonts are in `fonts.h`; the boot logo (`RC_logo`) is an XBM in
`images.h`.

## Helper functions (`display.cpp`)

- `get_time_string(seconds)` → `"S"` if < 60 s, else `"M:SS"` (zero-padded seconds).
- `get_score_string()` → `"<my>:<opp>"` from `module_get_my_score()`/`opponent_score()`.

## Screens (current behavior)

| Function | State | Content |
|---|---|---|
| `display_screen_init()` | `STM_INIT` | `RC_logo` full-screen XBM + bottom-right `"v <MAJOR>.<MINOR>"` |
| `display_screen_wait_for_connection()` | `STM_DISCONNECTED` | 64×64 **QR code of the BLE MAC** (left), `"Wait for\nconnection"` text + MAC split over two lines (right) |
| `display_screen_play()` | `STM_PLAY` | `"PLAY"` top; large 2-char `indicator` (split into two glyphs at x=41 and x=85, `DialogInput_bold_50`); `score` at bottom |
| `display_screen_stop()` | `STM_STOP` | Two filled side bars (`fillRect`) framing the screen; `"STOP"` top; large `indicator`; `score` bottom |
| `display_screen_damage(time)` | `STM_DAMAGE` | `"PENALTY - <indicator>"` top; large countdown (`Dialog_plain_40`); `score` bottom |
| `display_screen_half_break(time)` | `STM_HALF_TIME` | `"HALFTIME - <indicator>"` top; large countdown; `score` bottom |
| `display_screen_game_over()` | `STM_GAME_OVER` | `"GAME OVER"` top; large **score** (`Dialog_plain_40`); `indicator` small at bottom |

Each screen does `display.clear()` → draw → `display.display()`. `invertDisplay()` calls are
present but commented out.

## QR / MAC connection behavior

- On the wait screen, `qrcode.init(64, 64)` then `qrcode.create(mac_string)` renders a QR of
  the **Bluetooth MAC** (`BLE_MAC_to_string()`), the same value embedded in the advertised
  name `RCJs-m_<MAC>`.
- The MAC is also printed as text: `mac.substring(0,9)` on line 1, `mac.substring(9)` on
  line 2 (splitting the `AA:BB:CC:DD:EE:FF` string).
- The mobile app is expected to scan the QR (or read the name) to identify/connect to the
  correct module.

## Score display

- Maintained by `my_score` / `opponent_score` globals (`functions.cpp`).
- Set via `BLE_MSG_SET_SCORE` (both bytes) and `BLE_MSG_GAME_OVER` (both bytes).
- Shown as `"my:opp"` on PLAY/STOP/PENALTY/HALFTIME screens (bottom) and large on GAME OVER.

## Indicator (team/robot label) display

- `module_indicator`, default `"--"` (`DEFAULT_INDICATOR`).
- Set via `BLE_MSG_SET_NAME` (2 ASCII chars).
- Rendered as two large glyphs on PLAY/STOP; inline in PENALTY/HALFTIME titles; small on
  GAME OVER. Only the first 1–2 characters are used.

## Planned RGB LED behavior — PROPOSED, NOT IMPLEMENTED

> The following are **design ideas only**. No RGB LED code exists; the pin/type is unknown
> (see [05](05_hardware_mapping.md)). Listed to seed future design discussion — do not build
> until the schematic confirms the LED.
>
> ⚠️ **When you do implement it:** the on-board LED has its **Red/Green pads swapped**
> (footprint bug — the real `TC5050RGBF08` is G,R,B but the footprint is R,G,B), so **IO27
> lights green and IO24 lights red**. Drive IO24 for red / IO27 for green, or fix the
> footprint in a future board revision. See [05](05_hardware_mapping.md) / the hardware
> reference.

| State | Proposed LED idea (unconfirmed) |
|---|---|
| `STM_DISCONNECTED` | slow blue/white pulse "waiting" |
| `STM_PLAY` | solid green |
| `STM_STOP` | solid red |
| `STM_DAMAGE` | amber/orange, maybe blinking with countdown |
| `STM_HALF_TIME` | amber steady |
| `STM_GAME_OVER` | dim white / off |

## Planned buzzer behavior — PROPOSED, NOT IMPLEMENTED

> Same caveat: no buzzer code exists; pin and passive/active type unknown.

| Event | Proposed buzzer idea (unconfirmed) |
|---|---|
| BLE connected | short single beep |
| `PLAY` | short rising beep |
| `STOP` | short low beep |
| Penalty start / countdown end | distinct beep pattern |
| Self-penalty request acknowledged | confirmation beep |
| Power dip (supercap) | optional warning tone |

## Source files reviewed

`display.cpp/.h`, `functions.cpp`, `fonts.h` (referenced), `images.h` (referenced).

## Open questions

- Confirm OLED geometry is 128×64 on the new board (assumed from `drawXbm` dimensions).
- Desired RGB LED / buzzer semantics from the maintainer (the tables above are guesses).
- Should display feedback and LED/buzzer be unified behind one `feedback`/HAL module?
</content>

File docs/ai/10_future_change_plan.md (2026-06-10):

# 10 — Future Change Plan (Staged)

A safe, staged plan for adding the new ESP32-C5 / V7-2026 hardware features **after** the
schematic is provided. Each stage is independently buildable, testable, and revertible.
**Do not start Stage 2+ until Stage 1 confirms the pin map.**

> Cross-cutting rules:
> - Keep BLE wire compatibility: **append** new `ble_msg_id` values before `BLE_MSG_MAX_ID`;
>   never reorder existing ones (see [03](03_ble_protocol.md)).
> - Mirror any setup/loop change in **both** `RCj_comm_module.ino` and `main/app_main.cpp`
>   (see [02](02_firmware_architecture.md)).
> - Bump `FW_VERSION_MINOR` in `definitions.h` to match each release tag.
> - One feature per branch/PR; keep diffs small for easy rollback.

## Stage 1 — Verify schematic & pin mapping (BLOCKER) — ✅ DONE (2026-05-31)

- ✅ Schematic in repo: `pcb_schematic/SCH_Schematic1_2026-05-31.pdf`; pin reference:
  `docs/ai/ESP32C5_RCJ_modul_hardware_reference.md`. All pins documented in
  [05_hardware_mapping.md](05_hardware_mapping.md).
- ✅ Confirmed current firmware pins **match** the V7 board (I2C, both buttons, both outputs).
- ✅ New-peripheral pins known: RGB R/G/B = IO27/IO24/IO23 (active-high, common-cathode),
  buzzer = IO26 (pin 27), B3 = IO6/SW2, UART1 = IO4/IO5, GPIO28 on H1.
  ⚠️ **RGB Red/Green are swapped on the real board** (footprint bug): IO27 lights green,
  IO24 lights red. The Stage 3 RGB driver must account for this (drive IO24=red, IO27=green)
  or the footprint must be corrected in a board revision. See [05](05_hardware_mapping.md).
- **Remaining before Stage 3+:** decide whether to keep or delete the commented C6 block in
  `definitions.h`.

## Stage 2 — Hardware abstraction / definitions

- Add the confirmed pins to `definitions.h` (e.g. `RGB_LED_GPIO`, `BUZZER_GPIO`,
  `BUTTON3_GPIO`, `VIN_SENSE_GPIO`) as **defines only**, plus `pinMode` setup in
  `module_init_gpios()` — no behavior yet.
- Consider introducing a thin `hardware.h`/HAL boundary so feature modules don't sprinkle
  raw GPIO numbers.
- **Test:** builds clean; existing behavior unchanged (outputs/display/BLE identical).
- **Rollback:** revert the definitions/pinMode additions.

## Stage 3 — RGB LED driver

- Add `rgb_led.cpp/.h` (or extend a `feedback` module). Pick the driver per LED type
  (addressable WS2812 via RMT, or 3× PWM channels for a discrete RGB).
- Drive it from state transitions in `state_machine.cpp` (hook into the existing
  `state_changed` path), with a confirmed color map (replace the proposed table in
  [06](06_display_and_user_feedback.md) with the agreed one).
- **Test:** observe color per state on hardware; ensure no timing impact on the 1 ms loop.
- **Rollback:** compile-time flag (`#define FEATURE_RGB_LED`) to disable.

## Stage 4 — Buzzer driver

- Add `buzzer.cpp/.h`. If passive, use LEDC/`tone`-style PWM; if active, simple on/off.
- Make beeps **non-blocking** (no `delay()` in the loop — use a millis-based scheduler) to
  avoid stalling BLE/display.
- Trigger on events (connect, play, stop, penalty, self-penalty ack) per agreed semantics.
- **Test:** verify beeps don't delay output-pin updates or BLE processing.
- **Rollback:** `#define FEATURE_BUZZER` guard.

## Stage 5 — Define third-button behavior

- Wire `BUTTON3_GPIO` and implement its agreed function (menu / channel / manual control —
  TBD with maintainer). Reuse/extend the debounce pattern in `functions.cpp`.
- Re-examine the **shared `BUTTON_GPIO`** disconnect+penalty logic; with three buttons,
  consider separating roles cleanly to remove the long-press/double-press overlap.
- **Test:** all button combinations; confirm no regressions to disconnect/self-penalty.
- **Rollback:** keep new button handling behind a guard; old two-button logic intact.

## Stage 6 — Supercapacitor / power-loss behavior

- Only if a measurable signal exists (VIN-sense ADC or power-good GPIO confirmed in Stage 1).
- On detected dip: enter a safe state (outputs LOW or hold last? — confirm with rules),
  optionally flash LED / beep / send a BLE notification, and persist minimal state if needed.
- Keep the BLE link alive across the dip (the whole point of the supercap).
- **Test:** bench power-interrupt test; measure ride-through time.
- **Rollback:** guard; default to no power monitoring (current behavior).

## Stage 7 — Display / feedback integration

- Unify OLED + RGB LED + buzzer behind a single per-state `feedback` update so all outputs
  stay consistent (one source of truth driven by `stm_update`).
- Add any new screens (e.g. menu for button 3, low-power warning).
- Fix the `STM_DISCONNECTED` redraw gating if score/name should update live.
- **Test:** visual review of every state across all feedback channels.

## Stage 8 — Docs, tests, build/release

- Update `docs/ai/05` (final pin map), `06` (final LED/buzzer maps), `09` (close resolved
  questions), and the public `README.md`.
- Add/refresh any host-side or on-target smoke tests if introduced.
- Verify CI build (`idf.py build` via the workflow) and the web flasher still work; tag a new
  `fw-vX.Y` release.

## Risk & rollback summary

| Risk | Mitigation |
|---|---|
| BLE protocol break | Append-only enum; test against the real app before release |
| Loop stalls from blocking LED/buzzer/power code | Non-blocking, millis-based; measure loop time |
| Entry-point divergence | Edit `.ino` and `main/app_main.cpp` together (or retire `.ino`) |
| Wrong pin assumptions | Stage 1 gate; never guess from renders |
| Hard-to-revert changes | One feature per PR + compile-time `FEATURE_*` guards |
| C6 vs C5 confusion | Decide target support explicitly in Stage 1 |

## Source files reviewed

All `docs/ai/*`, firmware sources, workflow, README.
</content>

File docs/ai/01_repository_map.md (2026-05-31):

# 01 — Repository Map

## Top-level tree (tracked + notable untracked)

> **2026-05-31 cleanup:** the old 2024/v3 (C6) design artifacts were removed from `master`
> (`mobileAPP/`, the 2024 PDF, old `SCH.pdf`/`.epro`/Altium export, `pcb_library/`,
> `jlcpcb_gerbers/`, the `modul_v3.*` CAD, and the old module images). `master` now keeps only
> the **new V7** schematic + renders. The mobile app moved to its own repo
> (`robocup-junior/soccer-referee-app`, on Google Play). The legacy C6 hardware files still
> live in git history and on the `legacy/esp32-c6` branch.

```
.
├── README.md                          # Public docs — describes the CURRENT V7/2026 (C5) HW
├── LICENSE
├── .github/workflows/
│   └── firmware-release.yml           # CI (master): build C5 + GitHub Release + Pages flasher
│                                       #   (legacy/esp32-c6 also has firmware-release-legacy-c6.yml)
├── firmware/RCj_comm_module/          # The firmware (see below)
├── web/flasher/                       # Static Web-Serial flasher site (deployed to Pages)
├── tools/
│   └── prepare_firmware_release.py    # Packages build output + flasher manifest/version
├── pcb_schematic/
│   └── SCH_Schematic1_2026-05-31.pdf  # NEW V7/2026 schematic (ESP32C5_RCJ_modul, V1.0) — CURRENT
├── 3d_model/
│   └── hub_board.step                 # EV3/SPIKE hub accessory CAD (binary)
├── .readme_images/
│   ├── 3D_PCB1_2026-05-21 v4{,1,2}.png # renders of the NEW V7/2026 board (v41 = README/flasher hero)
│   └── hub_image.png                  # hub accessory photo
├── build/                             # (untracked) stray top-level build dir
└── docs/ai/                           # THIS documentation set
    └── ESP32C5_RCJ_modul_hardware_reference.md  # maintainer V7 pinout (authoritative HW source)
```

## Firmware folder detail

```
firmware/RCj_comm_module/
├── RCj_comm_module.ino     # Arduino-IDE sketch entry point (setup/loop)
├── definitions.h           # FW version, BLE/UART constants, GPIO pin map (C5 only; C6 map on legacy branch)
├── ble.cpp / ble.h         # BLE server, NUS UUIDs, RX/TX characteristics, server callbacks
├── ble_processing.cpp/.h   # ble_msg_t struct, ble_msg_id enum, RTOS queue, command dispatch
├── state_machine.cpp/.h    # stm_states enum, output-pin control, timers
├── display.cpp / display.h # SSD1306 OLED screen rendering (per state)
├── functions.cpp/.h        # MAC→string, score/indicator state, GPIO init, button handling
├── fonts.h                 # Bitmap fonts for the OLED
├── images.h                # XBM logo (RC_logo) for boot screen
├── CMakeLists.txt          # ESP-IDF top project file (sets IDF_TARGET=esp32c5)
├── sdkconfig.defaults      # ESP-IDF config: target C5, NimBLE peripheral, FreeRTOS 1000 Hz
├── .gitignore              # ignores build/, managed_components/, sdkconfig, .vscode/, etc.
├── main/
│   ├── app_main.cpp        # ESP-IDF entry point (app_main → initArduino + setup/loop)
│   ├── CMakeLists.txt      # Registers all ../*.cpp + bundled libs as the "main" component
│   └── idf_component.yml   # Pulls espressif/arduino-esp32 ^3.3.0
├── libraries/              # Vendored Arduino libraries (source, committed):
│   ├── ESP8266_and_ESP32_OLED_driver_for_SSD1306_displays/  # ThingPulse SSD1306 driver
│   ├── QRcodeDisplay/                                        # QR encoder + frames
│   └── QRcodeOled-2.0.0/                                     # QR-on-OLED adapter
├── build/                  # (untracked, gitignored) prior ESP-IDF build output
└── managed_components/     # (untracked, gitignored) IDF-fetched components (arduino-esp32, …)
```

## Source vs generated / vendored

| Category | Paths |
|---|---|
| **Firmware source (edit these)** | `firmware/RCj_comm_module/*.cpp`, `*.h`, `*.ino`, `main/app_main.cpp`, `main/CMakeLists.txt`, `CMakeLists.txt`, `sdkconfig.defaults`, `main/idf_component.yml` |
| **Vendored libs (avoid editing)** | `firmware/RCj_comm_module/libraries/**` (third-party OLED + QR code) |
| **Tooling** | `tools/prepare_firmware_release.py`, `.github/workflows/firmware-release.yml` |
| **Web flasher source** | `web/flasher/{index.html,app.js,styles.css,.nojekyll}` |
| **Generated / fetched (gitignored, do not commit/edit)** | `firmware/RCj_comm_module/build/`, `managed_components/`, `sdkconfig`, `dependencies.lock`, top-level `build/`, CI `dist/` |
| **Release artifacts (produced by CI, attached to Release)** | `dist/firmware/rcj_comm_module-<tag>{,-bootloader,-partition-table,-merged}.bin`, `dist/manifest.json`, `dist/version.json`, `dist/release-notes.md` |
| **Hardware design (V7, binary — for reference)** | `pcb_schematic/SCH_Schematic1_2026-05-31.pdf`, `3d_model/hub_board.step` |
| **Images** | `.readme_images/3D_PCB1_2026-05-21 v4{,1,2}.png` (V7 renders, v41 = hero), `hub_image.png` |

## Files present but not (fully) analyzed

These are binary or non-text and were not opened beyond noting their existence:

- `pcb_schematic/SCH_Schematic1_2026-05-31.pdf` (V7 schematic — captured in the HW reference doc)
- `3d_model/hub_board.step` (hub accessory CAD)

> The old 2024/C6 binaries (`SCH.pdf`, `.epro`, Altium export, Eagle/Altium libs, `modul_v3`
> CAD, JLCPCB gerbers, the 2024 PDF, the APK zip) were removed from `master` on 2026-05-31; see
> the cleanup note at the top. They remain in git history and on `legacy/esp32-c6`.

## Source files reviewed

`git ls-files`, directory tree, `firmware/RCj_comm_module/.gitignore`, the three new-board
render PNGs, `build/flasher_args.json`.
</content>

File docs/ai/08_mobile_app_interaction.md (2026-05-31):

# 08 — Mobile App Interaction

The mobile referee/control app lives in its **own repository**:
[`robocup-junior/soccer-referee-app`](https://github.com/robocup-junior/soccer-referee-app),
and is published on
[Google Play](https://play.google.com/store/apps/details?id=com.robocup.rcj_soccer). It is
**not source-controlled in this repo** (the old `mobileAPP/` APK zip was removed on
2026-05-31). Everything below is **inferred** from the firmware's BLE behavior, the public
`README.md` ("Mobile app" section), and commit history. Treat the app's exact UI as
**unknown / to confirm** — check the app repo for specifics.

## What can be inferred about the app

- It is a BLE central that connects to a peripheral advertising as `RCJs-m_<MAC>` and uses
  the **Nordic UART Service** (`6E400001-...`). See [03](03_ble_protocol.md).
- It can **scan the QR code** (BLE MAC) shown on the module's "wait for connection" screen
  to identify/select the right module.
- It sends one-byte-id command frames (`[msg_id][payload...]`) over the RX characteristic.
- It receives notifications on the TX characteristic: `PING` echoes, `FW_VERSION` reply, and
  the module-initiated `ASK_FOR_PENALTY` / `DISCONNECT` messages.
- Made by "Mato Faltus" (README Hall of Fame). Published on Google Play; source at
  [`robocup-junior/soccer-referee-app`](https://github.com/robocup-junior/soccer-referee-app).

## BLE command mapping (app action → firmware)

| App action (from README "How to control app") | Likely BLE message | Firmware effect |
|---|---|---|
| Double-click robot button → start | `BLE_MSG_PLAY` | `STM_PLAY`, OUT HIGH |
| Double-click robot button → stop | `BLE_MSG_STOP` | `STM_STOP`, OUT LOW |
| (Penalty action) | `BLE_MSG_DAMAGE` (+ uint32 ms) | `STM_DAMAGE` + countdown |
| Halftime | `BLE_MSG_HALF_BREAK` (+ uint32 ms) | `STM_HALF_TIME` + countdown |
| End game | `BLE_MSG_GAME_OVER` (+ scores) | `STM_GAME_OVER` |
| Double-click score → +1 | `BLE_MSG_SET_SCORE` (new my:opp) | updates score display |
| Hold score number → −1 | `BLE_MSG_SET_SCORE` (new my:opp) | updates score display |
| Set team/robot label | `BLE_MSG_SET_NAME` (2 chars) | updates indicator |
| Connection settings (hold robot button) | n/a (app-side) | — |
| "Reset all timers / start+stop all robots" | sequence of PLAY/STOP/timer msgs | per message |

> The README control hints are terse and describe **app-side gestures**, not the wire
> protocol. The mapping above is the best-effort correspondence; confirm against the app.

## Score control

- Firmware stores `my_score` / `opponent_score` (0–255 each, single byte).
- Updated only by `BLE_MSG_SET_SCORE` and `BLE_MSG_GAME_OVER`. The "double-click to +1 /
  hold to −1" logic lives **in the app**; the module just receives the resulting values.

## Penalty / self-penalty flow

Two distinct paths:

1. **Referee-initiated penalty (app → module):** `BLE_MSG_DAMAGE` with a 4-byte big-endian
   millisecond duration → `STM_DAMAGE` countdown, outputs LOW.
2. **Self-penalty request (module → app):** local **double-press** of `BUTTON_GPIO` or
   `BUTTON2_GPIO` while in `STM_PLAY` sends `BLE_MSG_ASK_FOR_PENALTY` to the app
   (`functions.cpp` → `ble_msg_procesing_ask_for_penalty()`). The firmware does **not**
   change its own state on a self-penalty request — it is up to the app/referee to respond
   (presumably by sending `BLE_MSG_DAMAGE`). Added in commit `e423b0d`.

## Connection assumptions

- No pairing/bonding/encryption in firmware; the app connects to an open GATT server.
- Connection params are module-requested (15–30 ms interval, 3 s supervision timeout as of
  fw v0.97; was 20 s through v0.96).
- On disconnect the module re-advertises immediately and the robot is stopped.
- A 5 s hold of `BUTTON_GPIO` forces a disconnect from the module side (notifies the app via
  `BLE_MSG_DISCONNECT` first).

## Unknowns to ask about later

- Exact app→firmware message set the **current** app emits (does it use `PING`/`FW_VERSION`?).
- Units/encoding the app uses for penalty/halftime durations (firmware expects **ms,
  big-endian uint32**).
- How the app reacts to `BLE_MSG_ASK_FOR_PENALTY` (auto-penalty vs referee prompt).
- Whether the app depends on the legacy INDICATE behavior (pre-`ca23261`) or the new NOTIFY.
- App-side handling of reconnection and of the `RCJs-m_<MAC>` name / QR identity.

## Source files reviewed

`README.md`, `ble_processing.cpp/.h`, `functions.cpp`, `ble.cpp`, commit `e423b0d`.
(App source is in the separate `robocup-junior/soccer-referee-app` repo.)
</content>

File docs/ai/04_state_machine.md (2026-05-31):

# 04 — State Machine

Implemented in `state_machine.cpp` / `state_machine.h`. The active state is a single
`static stm_states current_state` plus a `static bool state_changed` one-shot flag.

## States (`stm_states` enum)

| State | Value | Entered by | Output pins | Display |
|---|---|---|---|---|
| `STM_INIT` | 0 | initial value at boot | (unchanged) | boot logo + version, then `delay(2000)` → `STM_DISCONNECTED` |
| `STM_DISCONNECTED` | 1 | boot, or BLE disconnect | LOW (via state-change) | "Wait for connection" (QR + MAC) |
| `STM_PLAY` | 2 | `BLE_MSG_PLAY` | **HIGH** | PLAY screen (indicator + score) |
| `STM_STOP` | 3 | `BLE_MSG_STOP` | LOW | STOP screen |
| `STM_DAMAGE` | 4 | `BLE_MSG_DAMAGE` | LOW | PENALTY + countdown |
| `STM_HALF_TIME` | 5 | `BLE_MSG_HALF_BREAK` | LOW | HALFTIME + countdown |
| `STM_GAME_OVER` | 6 | `BLE_MSG_GAME_OVER` | LOW | GAME OVER + score |
| `STM_UPDATING` | 7 | **nothing (unused)** | — | none (no handler) |

> `STM_UPDATING` is declared but never set or handled. Likely reserved for an OTA/flashing
> screen. Safe to ignore today; do not assume it is reachable.

## Output pin behavior

`update_output_satet()` (note: misspelled "satet") is called by `stm_update()` **only when
`state_changed` is true**:

```c
robot_play ? (OUT1=HIGH, OUT2=HIGH, Serial "PLAY") : (OUT1=LOW, OUT2=LOW, Serial "STOP")
```

`robot_play` is set per state handler: `true` only in `state_play()`; `false` in
`state_stop()`, `state_damage()`, `state_half_break()`, `state_game_over()`.
`STM_INIT` and `STM_DISCONNECTED` do not set `robot_play` themselves — its value persists,
but on the **transition into** `STM_DISCONNECTED` the previous handler had already set it
`false` (or it is `false` from boot), so outputs are effectively LOW when disconnected.

## Per-loop rendering vs change-gated rendering

`stm_update()` runs every loop. Important asymmetry:

| State | Re-renders... |
|---|---|
| `STM_INIT` | every loop (calls `state_init()` unconditionally → but transitions away after first run) |
| `STM_DISCONNECTED` | **only when `state_changed`** (`if (state_changed) state_wait_connecting();`) |
| `STM_PLAY`, `STM_STOP`, `STM_DAMAGE`, `STM_HALF_TIME`, `STM_GAME_OVER` | **every loop** |

Consequences:
- The penalty/halftime **countdown updates live** because those screens redraw each loop
  and recompute `get_remaining_time()`.
- A `SET_SCORE` / `SET_NAME` received while in `STM_DISCONNECTED` is stored but not drawn
  until a state change forces a redraw.

## Timer behavior

- `stm_set_timer(ms)` sets `timer_stop = millis() + ms`.
- `get_remaining_time()` returns `max(0, (timer_stop - millis())/1000)` seconds.
- `BLE_MSG_DAMAGE` and `BLE_MSG_HALF_BREAK` set the timer (big-endian uint32 ms) **then**
  switch state; the screen counts down to 0.
- **The firmware does NOT auto-transition when the timer reaches 0.** It only displays `0`.
  Resuming play requires the app to send `BLE_MSG_PLAY` (or `STOP`). Putting robots back is
  a referee/team action per the rules (public README), not an automatic firmware event.

### The `660000 ms` init timer (unexplained)

```c
int8_t stm_init() {
    stm_set_timer(660000); //DOTO why ist here this? WTF
    return ESP_OK;
}
```

- 660000 ms = **11 minutes**. The author's own comment questions why it is there.
- It is harmless unless a `STM_DAMAGE`/`STM_HALF_TIME` screen is somehow shown before any
  `BLE_MSG_DAMAGE`/`HALF_BREAK` arrives (those messages overwrite the timer anyway).
- **Do not "fix" this without understanding intent** — flagged as an open question.

## Transition triggers summary

| Trigger | Resulting state |
|---|---|
| Boot | `STM_INIT` → (after 2 s) `STM_DISCONNECTED` |
| BLE `onDisconnect` | `STM_DISCONNECTED` (+ advertising restarts) |
| `BLE_MSG_PLAY` | `STM_PLAY` |
| `BLE_MSG_STOP` | `STM_STOP` |
| `BLE_MSG_DAMAGE` | `STM_DAMAGE` (timer set first) |
| `BLE_MSG_HALF_BREAK` | `STM_HALF_TIME` (timer set first) |
| `BLE_MSG_GAME_OVER` | `STM_GAME_OVER` (scores set first) |

> Note: BLE **connect** does NOT change state (the `stm_set_state(STM_PLAY)` line in
> `onConnect` is commented out). After connecting, the module stays on the
> "Wait for connection" screen until the app sends an explicit command.

## Disconnect behavior

`MyServerCallbacks::onDisconnect` (BLE host context):
1. `device_connected = false`
2. `stm_set_state(STM_DISCONNECTED)`
3. Restart advertising.

On the next `stm_update()` the disconnected screen is drawn and outputs go LOW
(robot stops). The 5-second button-hold `ble_disconnect()` path additionally sends a
`BLE_MSG_DISCONNECT` notification to the app first, then calls `pServer->disconnect(...)`,
which routes through the same `onDisconnect`.

## Game over

`STM_GAME_OVER`: outputs LOW, screen shows final `score` (large) and `indicator` (small).
No automatic exit; stays until disconnect or a new command.

## Mermaid diagram

```mermaid
stateDiagram-v2
    [*] --> STM_INIT
    STM_INIT --> STM_DISCONNECTED: after 2s boot delay
    STM_DISCONNECTED --> STM_PLAY: BLE_MSG_PLAY
    STM_PLAY --> STM_STOP: BLE_MSG_STOP
    STM_PLAY --> STM_DAMAGE: BLE_MSG_DAMAGE
    STM_PLAY --> STM_HALF_TIME: BLE_MSG_HALF_BREAK
    STM_STOP --> STM_PLAY: BLE_MSG_PLAY
    STM_DAMAGE --> STM_PLAY: BLE_MSG_PLAY
    STM_HALF_TIME --> STM_PLAY: BLE_MSG_PLAY
    STM_PLAY --> STM_GAME_OVER: BLE_MSG_GAME_OVER
    STM_STOP --> STM_GAME_OVER: BLE_MSG_GAME_OVER
    STM_PLAY --> STM_DISCONNECTED: BLE disconnect
    STM_STOP --> STM_DISCONNECTED: BLE disconnect
    STM_DAMAGE --> STM_DISCONNECTED: BLE disconnect
    STM_HALF_TIME --> STM_DISCONNECTED: BLE disconnect
    STM_GAME_OVER --> STM_DISCONNECTED: BLE disconnect
    note right of STM_DAMAGE: counts down, no auto-exit
    note right of STM_HALF_TIME: counts down, no auto-exit
```
*(Any state can be driven to any other by the app; only the common edges are shown.)*

## Suspicious / noteworthy comments

- `state_machine.cpp:88` — `//DOTO why ist here this? WTF` on the `660000` init timer.
- `update_output_satet` — function name typo (cosmetic).
- `ble.cpp` `onConnect` — `//stm_set_state(STM_PLAY);` commented out.

## Source files reviewed

`state_machine.cpp/.h`, `ble.cpp`, `ble_processing.cpp`, `display.cpp`.

## Open questions

- Intended purpose of the `660000 ms` timer in `stm_init()`.
- Should the penalty/halftime timer auto-return to `STM_PLAY`/`STM_STOP` at 0, or is the
  app always responsible?
- Should `STM_DISCONNECTED` redraw on score/name updates (currently it does not)?
</content>

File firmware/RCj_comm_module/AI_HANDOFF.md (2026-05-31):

# AI Handoff: RCJ Soccer Communication Module Firmware and Flasher

This file summarizes the recent work so another AI agent can continue without reconstructing the context.

## Repository Context

- Repository path: `/home/mato/VSCode/soccer-communication-module`
- Firmware project path: `firmware/RCj_comm_module`
- Current branch: `master`
- Current firmware target: `ESP32-C5`
- Current firmware version in `definitions.h`: `0.96`
- Current release tag: `fw-v0.96`
- Important user rule: do not run `git push` unless the user explicitly asks for it in that turn.

At the last check, `git status --porcelain` showed unrelated untracked files:

```text
?? ".readme_images/3D_PCB1_2026-05-21 v4.png"
?? ".readme_images/3D_PCB1_2026-05-21 v41.png"
?? ".readme_images/3D_PCB1_2026-05-21 v42.png"
?? docs/
```

These were not touched during the flasher and firmware work.

## Recent Commit History

Relevant commits currently visible in `git log --oneline --decorate -n 8`:

```text
da1b91d (HEAD -> master, tag: fw-v0.96, origin/master, origin/HEAD) Bump firmware version to 0.96
20db907 Improve ESP32-C5 flasher reset
51a724e Fix ESP32-C5 web flasher reset
254ee77 fix: make release workflow repo explicit
4a9e18e Use GitHub Actions Pages deployment
40b3c8b Publish flasher site to gh-pages branch
5faed82 (tag: fw-v0.95) Add firmware release workflow and web flasher
ca23261 Improve BLE command latency and resilience
```

Verify remote state before assuming the release has run. If the tag is not on GitHub yet, the user must explicitly authorize pushing:

```sh
git push origin master
git push origin fw-v0.96
```

Do not run those commands without explicit user approval.

## Firmware BLE Work

The play/stop critical path is not server notify. It is:

1. Mobile app writes to the BLE RX characteristic.
2. `ble.cpp` `onWrite()` queues the message.
3. `ble_processing.cpp` maps message IDs such as `BLE_MSG_PLAY` and `BLE_MSG_STOP`.
4. `state_machine.cpp` changes module state and output pins.

Main firmware changes:

- TX characteristic changed from indication to notification.
  - Current code uses `BLECharacteristic::PROPERTY_NOTIFY`.
  - `ble_send_msg()` calls `pTxCharacteristic->notify()`.
  - Reason: indications require client acknowledgement and can serialize traffic, which is bad for fast multi-module play/stop control.

- RX characteristic supports write without response.
  - Current code uses `BLECharacteristic::PROPERTY_WRITE | BLECharacteristic::PROPERTY_WRITE_NR`.
  - Android/iOS apps should use write-without-response for fast play/stop bursts.

- BLE message queue is larger and handles bursts better.
  - `BLE_QUEUE_MAX_SIZE` is now `16`.
  - `queue_ble_msg()` drops the oldest queued message when full, then queues the newest message.

- BLE connection parameters are requested for NimBLE connections.
  - `BLE_CONN_INTERVAL_MIN = 12`, which is 15 ms.
  - `BLE_CONN_INTERVAL_MAX = 24`, which is 30 ms.
  - `BLE_CONN_LATENCY = 0`.
  - `BLE_CONN_TIMEOUT = 2000`, which is 20 s because units are 10 ms.
  - The 20 s timeout is intentional. Earlier aggressive timeout behavior caused modules to disconnect after missed pings or latency spikes. The user wants modules to stay connected as strongly as possible.

- BLE advertised name now includes the MAC-derived suffix.
  - Current define: `#define BLE_NAME "RCJs-m_" + BLE_MAC_to_string()`
  - Reason: iPhones do not expose MAC addresses, so the app can identify modules from the BLE name.

- Firmware version was bumped:
  - `FW_VERSION_MAJOR = 0`
  - `FW_VERSION_MINOR = 96`

## Mobile App Expectations

The mobile app should:

- Write play/stop commands to the RX characteristic, not wait on module notifications for this path.
- Use write-without-response for the RX characteristic.
- Send play/stop to all open `BluetoothGatt` connections without waiting for each device callback before moving to the next device.
- Avoid indication-based retry logic for play/stop.
- Optional robustness: send the same play/stop command twice with a 5-10 ms spacing.

## GitHub Actions and Release Flow

Workflow file:

```text
.github/workflows/firmware-release.yml
```

Current behavior:

- Trigger: pushed tags matching `fw-*` or `v*`.
- Firmware build uses `espressif/esp-idf-ci-action@v1`.
- ESP-IDF version: `v5.5.4`.
- Target: `esp32c5`.
- Project path: `firmware/RCj_comm_module`.
- Release preparation runs:

```sh
python ../../tools/prepare_firmware_release.py \
  --project-dir . \
  --web-src ../../web/flasher \
  --output-dir ../../dist \
  --version ${{ github.ref_name }}
```

The workflow:

1. Builds firmware.
2. Generates release assets and the Pages site under `dist/`.
3. Uploads the `firmware-release` artifact.
4. Creates or updates the GitHub Release.
5. Deploys the web flasher with modern GitHub Pages Actions:
   - `actions/configure-pages@v5`
   - `actions/upload-pages-artifact@v4`
   - `actions/deploy-pages@v4`

GitHub Pages must be configured to use GitHub Actions as the Pages source. The older `gh-pages` branch approach was discussed but superseded.

## Release Preparation Script

Script:

```text
tools/prepare_firmware_release.py
```

It:

- Reads `build/flasher_args.json`.
- Copies:
  - application binary
  - bootloader binary
  - partition table binary
- Merges binaries into a single flash image at offset `0x0` using `python -m esptool merge_bin`.
- Copies the static web flasher from `web/flasher`.
- Copies `.readme_images/modul_2024.png` into the flasher assets if present.
- Generates:
  - `manifest.json`
  - `version.json`
  - `release-notes.md`
- Includes flash settings in the manifest:
  - `flashMode`
  - `flashFreq`
  - `flashSize`

Known warning:

- With `esptool v5.2.0`, the current script emits deprecation warnings for `merge_bin`, `--flash_mode`, `--flash_freq`, and `--flash_size`.
- It still works. Future cleanup can switch to `merge-bin`, `--flash-mode`, `--flash-freq`, and `--flash-size`.

## Web Flasher

Files:

```text
web/flasher/index.html
web/flasher/app.js
web/flasher/styles.css
```

The flasher was changed from the ready-made `esp-web-install-button` to a custom Web Serial flasher because the standard button failed on ESP32-C5 native USB with:

```text
Installation failed
Failed to initialize. Try resetting your device or holding the BOOT button while clicking INSTALL.
```

The module does not expose BOOT/RESET buttons, and standard tools can enter the bootloader over native USB.

Current implementation:

- Imports `esptool-js@0.6.0` from:

```js
https://unpkg.com/esptool-js@0.6.0/bundle.js
```

- Uses Web Serial:

```js
const port = await navigator.serial.requestPort();
const transport = new Transport(port, false);
```

- Enters ESP32-C5 bootloader explicitly:

```js
await loader.main("usb_reset");
```

- Downloads `manifest.json` and `version.json`.
- Loads the merged firmware binary listed in the manifest.
- Flashes with:

```js
eraseAll: true
compress: true
```

- The UI no longer has an erase checkbox. It shows fixed text:

```text
Flash memory will be fully erased first.
```

Final reset:

- `loader.after("hard_reset", true)` did not reliably boot the new firmware.
- The user reported that flashing worked, but the module only booted after physically unplugging and reconnecting.
- Investigation found `esptool-js@0.6.0` hard reset behavior did not produce the needed full RTS pulse in this path.
- Current code manually resets over USB serial:

```js
const hardResetViaUsbSerial = async (transport) => {
  appendLog("Hard resetting via USB serial RTS pulse...");
  await transport.setDTR(false);
  await transport.setRTS(true);
  await sleep(200);
  await transport.setRTS(false);
  await sleep(200);
  await transport.setDTR(false);
};
```

The user physically tested this change and reported that the flasher works.

## Local Test Procedure

Local release generation was tested with:

```sh
GITHUB_REPOSITORY=robocup-junior/soccer-communication-module \
GITHUB_SHA=$(git rev-parse HEAD) \
/tmp/rcj-esptool-venv/bin/python tools/prepare_firmware_release.py \
  --project-dir firmware/RCj_comm_module \
  --web-src web/flasher \
  --output-dir /tmp/rcj-flasher-dist \
  --version fw-local-test
```

Local web server used for browser testing:

```sh
python3 -m http.server 8765 --directory /tmp/rcj-flasher-dist
```

Test URL:

```text
http://127.0.0.1:8765/
```

JavaScript syntax check:

```sh
node --input-type=module --check < web/flasher/app.js
```

The user confirmed physical flashing success after the manual RTS reset change.

## Remaining Risks and Follow-Up

- Do not push without explicit user instruction.
- Check whether `fw-v0.96` has actually been pushed to GitHub and whether the Actions release completed.
- If the GitHub release failed, inspect the `Firmware Release` workflow run first.
- If the flasher later fails to load, check CDN availability for `https://unpkg.com/esptool-js@0.6.0/bundle.js`.
- Consider vendoring `esptool-js` if offline or long-term release stability becomes important.
- Consider updating `prepare_firmware_release.py` to the non-deprecated esptool v5 CLI names.
- Verify the mobile app uses write-without-response and parallel fan-out for play/stop.
- Preserve the 20 s BLE supervision timeout unless the user explicitly asks for more aggressive disconnect detection.

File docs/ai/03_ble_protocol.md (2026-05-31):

# 03 — BLE Protocol

The module is a BLE **peripheral** (GATT server) using the **Nordic UART Service (NUS)**
UUID scheme. NimBLE stack (`CONFIG_BT_NIMBLE_ENABLED=y`).

## Device name / advertising

- Advertised name: `BLE_NAME = "RCJs-m_" + BLE_MAC_to_string()`
  (`definitions.h` + `functions.cpp`), e.g. `RCJs-m_AA:BB:CC:DD:EE:FF`.
  - **Why the MAC is in the name (per `AI_HANDOFF.md`):** iPhones do not expose the BLE
    MAC to apps, so the app identifies/selects modules by the advertised **name** instead.
- The MAC is the **Bluetooth** MAC: `esp_read_mac(base_mac, ESP_MAC_BT)`.
- The same MAC string is encoded into the **QR code** on the "wait for connection" screen.
- Advertising restarts automatically on disconnect (`MyServerCallbacks::onDisconnect`).

## UUIDs (`ble.cpp`)

| Role | UUID | Properties |
|---|---|---|
| Service | `6E400001-B5A3-F393-E0A9-E50E24DCCA9E` | NUS |
| RX (app → module, write) | `6E400002-B5A3-F393-E0A9-E50E24DCCA9E` | `WRITE` + `WRITE_NR` (write-without-response) |
| TX (module → app, notify) | `6E400003-B5A3-F393-E0A9-E50E24DCCA9E` | `NOTIFY` |

> Changed in commit `ca23261`: RX gained `WRITE_NR`, TX switched from `INDICATE` (with a
> `BLE2902` descriptor) to plain `NOTIFY`. **Any app expecting indications/CCCD on TX or
> requiring write-with-response on RX must be re-checked against this firmware.**

### Connection parameters (NimBLE only)

Requested on connect via `pServer->requestConnParams(...)` (`MyServerCallbacks::onConnect`
with `ble_gap_conn_desc`), from `definitions.h`:

| Constant | Value | Meaning |
|---|---|---|
| `BLE_CONN_INTERVAL_MIN` | 12 | 15 ms (units of 1.25 ms) |
| `BLE_CONN_INTERVAL_MAX` | 24 | 30 ms |
| `BLE_CONN_LATENCY` | 0 | no slave latency |
| `BLE_CONN_TIMEOUT` | 300 | 3 s (units of 10 ms) — lowered from 2000/20 s in fw v0.97 |

> **`BLE_CONN_TIMEOUT` was lowered from 2000 (20 s) to 300 (3 s) in fw v0.97 (2026-05-31).**
> - History: the 20 s value was originally chosen on purpose (`AI_HANDOFF.md`) because
>   shorter timeouts caused modules to disconnect on missed pings / latency spikes.
> - **Problem found in testing (two effects of the same value):**
>   1. *Reconnect:* on link loss the phone's BLE stack kept the stale connection alive until
>      the supervision timeout expired — up to ~20 s — before reconnecting. Unacceptable in a
>      match.
>   2. *Safety/fairness:* on a **silent** link loss the module's `onDisconnect` only fires at
>      supervision-timeout expiry, so the robot could keep **playing for up to ~20 s** before
>      the module fail-safes to STOP.
> - **Change made:** `BLE_CONN_TIMEOUT = 300` (3 s). Trades a little robustness against brief
>   dropouts for much faster reconnect *and* faster fail-safe stop. The C5 supercap reduces
>   the original need for a long timeout (brief power dips no longer reset the module).
> - **Spec constraint:** supervision timeout (ms) must be `> (1 + latency) * interval_max * 2`.
>   With `latency=0` and `interval_max=30 ms`, the floor is ~60 ms, so 3 s is safely valid.
> - ⚠️ Validate on real hardware that 3 s does not cause spurious disconnects during normal
>   play (the original 20 s was anti-flap); revisit upward if flapping reappears.

## Message framing

Defined by `ble_msg_t` (`ble_processing.h`) and parsed in `MyCallbacks::onWrite`:

```
byte[0]      = msg_id          (one of ble_msg_id)
byte[1..N]   = payload data    (msg-specific; up to BLE_DATA_MAX_LENGTH = 10 bytes)
```

- `ble_msg_t.data_length` = received length − 1 (the id byte is not counted).
- Accepted only if `1 <= length <= BLE_DATA_MAX_LENGTH + 1` (i.e. id + up to 10 data bytes).
  Empty or oversized writes are silently ignored.
- Valid messages are pushed to the queue (overwrite-oldest if full). Dispatch happens later
  in the main loop (`ble_msg_processing`), one message per loop iteration.

## Message IDs (`ble_msg_id` enum, `ble_processing.h`)

Values are the enum ordinals (no explicit numbering), so order matters — **do not reorder**
without updating the app:

| ID | Name | Value | Direction | Handled in RX switch? |
|----|---|---|---|---|
| `BLE_MSG_PING` | ping | 0 | app → module (echo back) | yes |
| `BLE_MSG_FW_VERSION` | firmware version | 1 | app → module (reply) | yes |
| `BLE_MSG_SET_NAME` | set indicator | 2 | app → module | yes |
| `BLE_MSG_SET_SCORE` | set score | 3 | app → module | yes |
| `BLE_MSG_PLAY` | play | 4 | app → module | yes |
| `BLE_MSG_STOP` | stop | 5 | app → module | yes |
| `BLE_MSG_DAMAGE` | penalty/damage | 6 | app → module | yes |
| `BLE_MSG_HALF_BREAK` | halftime | 7 | app → module | yes |
| `BLE_MSG_GAME_OVER` | game over | 8 | app → module | yes |
| `BLE_MSG_DISCONNECT` | disconnect | 9 | **module → app** | no (outbound only) |
| `BLE_MSG_ASK_FOR_PENALTY` | self-penalty request | 10 | **module → app** | no (outbound only) |
| `BLE_MSG_MAX_ID` | sentinel | 11 | — | — |

## Per-message payload and side effects (`ble_msg_processing`)

| Message | Payload (data bytes) | Effect | Affects |
|---|---|---|---|
| `BLE_MSG_PING` | arbitrary, echoed | Replies with the **same** bytes (`data_length + 1`) on TX | link check |
| `BLE_MSG_FW_VERSION` | none | Replies `[id, FW_VERSION_MAJOR, FW_VERSION_MINOR]` (3 bytes) | — |
| `BLE_MSG_SET_NAME` | `data[0]`, `data[1]` = two ASCII chars | `module_set_indicator(c0 + c1)` | display only |
| `BLE_MSG_SET_SCORE` | `data[0]` = my score, `data[1]` = opponent score | sets both scores | display only |
| `BLE_MSG_PLAY` | none | `stm_set_state(STM_PLAY)` | **OUT1/2 → HIGH**, display |
| `BLE_MSG_STOP` | none | `stm_set_state(STM_STOP)` | **OUT1/2 → LOW**, display |
| `BLE_MSG_DAMAGE` | `data[0..3]` = uint32 **big-endian** milliseconds | `stm_set_timer(ms)`, `stm_set_state(STM_DAMAGE)` | OUT1/2 → LOW, countdown |
| `BLE_MSG_HALF_BREAK` | `data[0..3]` = uint32 **big-endian** milliseconds | `stm_set_timer(ms)`, `stm_set_state(STM_HALF_TIME)` | OUT1/2 → LOW, countdown |
| `BLE_MSG_GAME_OVER` | `data[0]` = my score, `data[1]` = opponent score | sets scores, `stm_set_state(STM_GAME_OVER)` | OUT1/2 → LOW, display |
| `BLE_MSG_DISCONNECT` | — (sent by module) | Sent in `ble_disconnect()` before dropping the link | — |
| `BLE_MSG_ASK_FOR_PENALTY` | — (sent by module) | Sent on local double-press, **only while `STM_PLAY`** | — |

### Which messages affect the robot PLAY/STOP outputs

- **HIGH (play):** `BLE_MSG_PLAY`.
- **LOW (stop):** `BLE_MSG_STOP`, `BLE_MSG_DAMAGE`, `BLE_MSG_HALF_BREAK`,
  `BLE_MSG_GAME_OVER`, and a BLE **disconnect** (→ `STM_DISCONNECTED`, which on the next
  state-change cycle leaves `robot_play=false`).

### Which messages affect the display only

`BLE_MSG_SET_NAME`, `BLE_MSG_SET_SCORE` (these do not change state; the new values appear
the next time a screen re-renders). `BLE_MSG_GAME_OVER` also updates the score.

> ⚠️ **Render-timing nuance:** `STM_DISCONNECTED` only redraws when `state_changed` is set,
> and `STM_PLAY`/`STM_STOP` redraw every loop. So a `SET_SCORE`/`SET_NAME` received while
> idle in `STM_DISCONNECTED` will not visibly update until the next state change. See
> [04](04_state_machine.md).

## Timer payload encoding

`BLE_MSG_DAMAGE` / `BLE_MSG_HALF_BREAK` decode the duration as **big-endian** uint32:

```c
stm_set_timer((uint32_t)data[0]<<24 | (uint32_t)data[1]<<16 | (uint32_t)data[2]<<8 | data[3]);
```

Value is in **milliseconds**; the display shows it as `seconds` or `m:ss` (see display doc).

## Error / unknown-message behavior

- Unknown `msg_id`: `default` case does nothing (the error `Serial.println` is commented out).
- Malformed length (0 or > 11 bytes total): dropped at `onWrite`, never queued.
- No negative ACK / error reply is ever sent to the app.

## Protocol risks & compatibility notes

- **Enum ordinals are the wire IDs.** Inserting/removing/reordering any `ble_msg_id` member
  shifts every later ID and breaks the app. If you must extend, **append before
  `BLE_MSG_MAX_ID`** and keep existing order.
- TX changed from INDICATE→NOTIFY and RX gained WRITE_NR (`ca23261`) — verify the shipped
  app matches.
- No authentication/pairing logic in firmware; any BLE client can write commands.
- `BLE_DATA_MAX_LENGTH = 10` caps payloads; current largest payload is 4 bytes (timers).
- `BLE_MSG_PING` echo length uses `data_length + 1`; very large echoes are bounded by the
  10-byte input cap.

## Source files reviewed

`ble.cpp/.h`, `ble_processing.cpp/.h`, `definitions.h`, `functions.cpp`, commit `ca23261`.

## Open questions

- Exact app-side expectation for `BLE_MSG_FW_VERSION` reply format (3 bytes assumed).
- Does the app rely on `BLE_MSG_DISCONNECT` notification arriving before link drop?
- Are there app→module messages the app sends that the firmware silently ignores today?
</content>

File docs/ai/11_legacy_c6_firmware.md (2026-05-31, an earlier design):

# 11 — Legacy ESP32-C6 Firmware: Strategy & Release Plan

Plan for shipping a **final, maintained legacy firmware** for the old 2024 ESP32-C6 module
after `master` becomes ESP32-C5-only. **Nothing in this document has been executed** — no
branch created, no firmware changed, no tags pushed. Each step below is gated on explicit
maintainer approval (and the project rule: never `git push` unless asked in that turn).

## Decisions locked in (2026-05-31)

| Topic | Decision |
|---|---|
| Codebase compatibility | Drop C6 support from `master`; `master` is C5-only going forward |
| Legacy distribution | Final C6 binaries as **GitHub Release assets** + flashing docs; small "old module?" link from the C5 flasher page. No legacy web-flasher page. |
| Legacy maintenance | Long-lived **`legacy/esp32-c6` branch**; critical fixes cherry-picked from `master`; releases tagged **`legacy-c6-vX.Y`** |
| Legacy CI | **Auto-build** the C6 binaries on `legacy-c6-*` tags (GitHub Actions). Pages/web flasher stays C5-only. |
| C6 flashing access | Two documented paths: (a) the **special flashing/jig PCB**, (b) **direct wiring to the right module pin header**. Both expose native-USB **and** UART. The C6 module has **no USB-C connector**. |

## Old C6 board reference (from `pcb_schematic/SCH.pdf`, "modula_2024" V0.1)

| Item | Detail |
|---|---|
| MCU | **ESP32-C6-MINI-1-N4** (4 MB flash, no PSRAM) |
| Power | `UA78M33CDCYR` LDO, VIN 5.3–25 V → 3.3 V, ~500 mA (no supercap) |
| Inputs | 2 buttons: SW1→`BUT_1`, SW2→`BUT_2` (10 kΩ pull-ups) |
| Outputs | `OUT_1`, `OUT_2` (1 kΩ series R6/R7) — robot start/stop |
| Display | I2C OLED (`SDA`/`SCL`) |
| Extra HW | **LIS3DHTR accelerometer** (I2C, unused by firmware); level-shifted UART via `TXS0102` + `LOGV` pin; USB D+/D- broken out on the U3 header (no connector) |
| Not present | RGB LED, buzzer, third button, supercap, USB-C — all C5-only |

> The current firmware only uses I2C OLED + 2 buttons + 2 outputs + BLE, all of which the C6
> board has. So today's `master` source, compiled for `esp32c6` with the C6 pin block, yields
> a **functionally complete** legacy build. The accelerometer stays unused.

## C6 pin map (the commented block in `definitions.h`)

```c
// ESP-C6
#define I2C_SDA_GPIO    6
#define I2C_SCL_GPIO    7
#define BUTTON_GPIO     18
#define BUTTON2_GPIO     9
#define OUTPUT1_GPIO    20
#define OUTPUT2_GPIO    19
```

These were the **working pins before the C5 migration** (commit `7f9fb81` added C5 and
commented out C6), so confidence is high. They are cross-consistent with the C6-MINI pinout
in `SCH.pdf` (SDA=IO6, SCL=IO7; USB on IO12/IO13; outputs on IO19/IO20). **Still must be
confirmed by a real build + smoke test on a C6 module before release** (see checklist).

## Git layout

```
master              ── ESP32-C5 only. Remove the commented C6 block from definitions.h.
                       Workflow triggers on fw-* / v*. Deploys C5 web flasher to Pages.

legacy/esp32-c6     ── Branched from the current C5-capable HEAD. On this branch:
                        • definitions.h: C6 pins ACTIVE (not commented), C5 block removed
                        • CMakeLists.txt: set(IDF_TARGET "esp32c6" ...)
                        • sdkconfig.defaults: CONFIG_IDF_TARGET="esp32c6" / *_ESP32C6=y
                        • workflow: trigger on legacy-c6-*, target esp32c6, NO Pages deploy
                       Tagged legacy-c6-vX.Y for each legacy release.
```

Rationale for a **branch, not just a tag**: the maintained policy means we may cherry-pick a
critical fix from `master` and cut a new `legacy-c6-v…` later. A branch makes that a normal
`git cherry-pick` + tag, with no need to recreate the C6 config each time.

## Build & artifacts (answers "is the .bin enough?")

A bare app `.bin` is **not** enough to flash a blank/erased chip. Three images are required
at target-specific offsets: **bootloader**, **partition table**, **app**. The existing
`tools/prepare_firmware_release.py` already merges them via `esptool merge_bin` into a single
image flashed at `0x0`. **That merged file is the one sufficient artifact.**

The C6 legacy release will publish (same tooling, just target `esp32c6`):

| File | Purpose |
|---|---|
| `rcj_comm_module-<ver>-merged.bin` | **Primary** — flash at `0x0` with full erase. Contains bootloader + partition table + app. |
| `rcj_comm_module-<ver>.bin` | App only (advanced / OTA-style) |
| `rcj_comm_module-<ver>-bootloader.bin` | Advanced (flash at the C6 bootloader offset) |
| `rcj_comm_module-<ver>-partition-table.bin` | Advanced (flash at `0x8000`) |
| `manifest.json`, `version.json` | Chip family, sizes, sha256 |

> `prepare_firmware_release.py` and the workflow are **target-agnostic**: they read chip and
> per-part offsets from `build/flasher_args.json` and derive `chipFamily = ESP32-C6`
> automatically. **No script changes needed** — only the IDF target. The C6 bootloader offset
> (which differs from the C5 `0x2000`) is handled by `merge_bin`, so the single merged image
> remains "flash at `0x0`."

## Flashing the legacy module (to be documented for users)

Both access methods reach the same module pins; pick whichever the user has:
- **(a) Flashing/jig PCB** — connect the module to the jig, then flash over native USB or UART.
- **(b) Direct pin-header wiring** — wire the right module header pins to a USB or USB-UART
  adapter.

Then either:
- **One-file (recommended):**
  `esptool --chip esp32c6 write_flash --erase-all 0x0 rcj_comm_module-<ver>-merged.bin`
- **Web/esptool-js (jig native-USB users):** point esptool-js at the merged bin, `0x0`,
  `eraseAll: true`, chipFamily `ESP32-C6`. (Optional future nicety; not built now.)
- **Parts (advanced):** flash bootloader/partition/app at their offsets via `esptool`.

### Flashing-method note (verified 2026-05-31 on real hardware)

**Use native USB — it is by far the easier path.** The C6's USB D+/D− (IO13/IO12) are
broken out on the **U3 header** (`USB_D+` / `USB_D-`, 6-pin `2541WV-06P`). Wiring those to a
USB port makes the module enumerate as **`/dev/ttyACM*`** (USB-Serial-JTAG); esptool then has
built-in auto-reset/download — no buttons. This is how the test board was flashed:
`esptool --chip esp32c6 -p /dev/ttyACM0 write_flash --erase-all 0x0 …-merged.bin` (worked
first try, hash verified).

**The level-shifted UART path is fiddly — note for whoever documents it:**
- On the schematic, the ESP **UART0** (`TXD0`/`RXD0` = `TX_ESP`/`RX_ESP`) goes through the
  **`TXS0102`** level shifter to **`TX_OUT`/`RX_OUT`** on the U3 header. The shifter is
  referenced/enabled by **`LOGV`** (must be 3.3 V) — if `LOGV` is unpowered the line is dead
  (symptom: esptool "No serial data received", *zero* bytes even on a plain reset).
- UART flashing also needs **manual download mode**: hold **IO9 (BOOT)** low, pulse **EN**,
  release IO9 — there is **no auto-reset circuit** on bare pin-header wiring (DTR/RTS not
  wired). Use **3.3 V logic** and a common GND.
- Given all that, prefer native USB for users; document UART only as a fallback.

## CI (legacy branch)

A workflow on `legacy/esp32-c6` (a copy/edit of `firmware-release.yml`) that:
- triggers on tags `legacy-c6-*`,
- builds with `espressif/esp-idf-ci-action` (ESP-IDF v5.5.4), **target `esp32c6`**,
- runs `prepare_firmware_release.py`,
- creates/updates a **GitHub Release** with the C6 bins + `manifest.json` + `version.json`
  + `release-notes.md`,
- **omits** the GitHub Pages jobs (Pages = C5 flasher only).

## Maintenance policy

- **First release = snapshot of current code** (already includes the BLE latency/resilience
  fix `ca23261`), plus the pre-release fixes in the checklist below.
- Afterward, cut a new `legacy-c6-v…` **only for a critical fix**, where *critical* =
  robot-fails-to-stop / robot-keeps-playing-after-link-loss / BLE-won't-connect /
  display-dead class bugs. Cosmetic/feature changes do **not** warrant a legacy release.
- Fix flow: land on `master` → `git cherry-pick` onto `legacy/esp32-c6` → tag `legacy-c6-vX.Y`.

## Pre-first-release checklist

**Must-fix (before the first legacy release):**
- [x] **Lower `BLE_CONN_TIMEOUT`** from `2000` (20 s) to **`300`** (3 s) — DONE on `master`
      in **fw v0.97** (2026-05-31). Safety/fairness: with 20 s, a robot could keep playing for
      up to ~20 s after a silent link loss before the module fail-safed to STOP; also fixes the
      slow phone reconnect. *(See [03](03_ble_protocol.md), [09](09_known_issues_and_open_questions.md),
      `project-ble-supervision-timeout`.)*
- [ ] **Cherry-pick the v0.97 timeout change onto `legacy/esp32-c6`** once that branch exists.

**Must-verify (gating, not bugs):**
- [x] **UART line is clean for serial-reading robots — DONE (2026-05-31).** Only `PLAY`/`STOP`
      are printed (other debug prints already commented); `Serial`→UART0 confirmed; release
      `sdkconfig.defaults` now silences bootloader/IDF/Arduino-HAL logs and pins console to
      UART0. A `sdkconfig.debug` overlay gives USB-C logging for development. **This config
      carries over to the legacy C6 branch** (verify it still applies for target esp32c6 —
      the symbols are target-independent). *(See [02](02_firmware_architecture.md#build-flavors-release-uart-clean-vs-debug-usb-verbose),
      [07](07_build_release_and_flasher.md).)*
- [x] Current source **compiles for `esp32c6`** — DONE (2026-05-31). Built on the
      `legacy/esp32-c6` branch with ESP-IDF v5.5.4 + arduino-esp32 ^3.3.0 + NimBLE; app image
      ~0xbe490 bytes, 26% free in the 1 MB app partition. Config: `IDF_TARGET=esp32c6`,
      `CONFIG_ESPTOOLPY_FLASHSIZE_4MB` (C6-MINI-1-N4 = 4 MB), C6 pin block active.
- [~] **C6 pin map — partially confirmed on real hardware (2026-05-31).** After flashing:
      **OLED renders** (I2C on IO6/IO7 ✅) and **BLE advertises + connects** ✅. Still to
      confirm: `OUT1`/`OUT2` (IO20/IO19) HIGH on PLAY / LOW on STOP & disconnect; both buttons
      (disconnect long-press IO18, penalty double-press IO18/IO9).
- [x] **Merged C6 bin flashes cleanly — DONE via native USB (2026-05-31).** `esptool --chip
      esp32c6 write_flash --erase-all 0x0 …-merged.bin` over the native USB-Serial-JTAG port
      (`/dev/ttyACM0`); hash verified. See the flashing-method note below.

**Not blocking (known, low risk — document, don't fix for legacy):**
- `stm_init()` `660000 ms` timer (`//DOTO … WTF`) — harmless; overwritten by DAMAGE/HALF_BREAK.
- `STM_DISCONNECTED` only redraws on state change (score/name updates not shown while idle) —
  cosmetic.
- Two entry points (`.ino` vs `main/app_main.cpp`) must stay in sync — maintenance hazard.
- Shared `BUTTON_GPIO` for disconnect + penalty — pre-existing behavior, unchanged on C6.

No true showstopper logic bug was found: the stop path is fail-safe (outputs LOW on
STOP/DAMAGE/HALF_BREAK/GAME_OVER and on disconnect), and the message queue keeps the newest
command when full.

## Staged execution (each step needs explicit go-ahead)

1. ✅ Land the `BLE_CONN_TIMEOUT` fix on `master` — done (300 / 3 s, fw v0.97).
2. Create `legacy/esp32-c6` from the C5-capable HEAD (then cherry-pick the v0.97 change).
3. On the legacy branch: activate C6 pins, set IDF target `esp32c6`, add the legacy workflow.
4. Verify a C6 build + smoke test on hardware.
5. Remove the commented C6 block from `master` (now redundant).
6. Tag `legacy-c6-v0.96` (or current version) → CI builds + publishes the Release.
7. Add a public-`README.md` "Legacy 2024 (ESP32-C6) modules" section + flashing docs, and a
   small link from the C5 flasher page.

## Open questions

- ~~Exact target value for `BLE_CONN_TIMEOUT`~~ — resolved: **300 (3 s)** in fw v0.97.
- Should the legacy release version track `master`'s `FW_VERSION` (e.g. `legacy-c6-v0.97`),
  or start its own legacy numbering?
- Do we want the optional esptool-js web path for jig users now, or defer indefinitely?

## Source files reviewed

`pcb_schematic/SCH.pdf`, `definitions.h`, `CMakeLists.txt`, `sdkconfig.defaults`,
`.github/workflows/firmware-release.yml`, `tools/prepare_firmware_release.py`,
`web/flasher/app.js`, `build/flasher_args.json`, and docs [03], [05], [07], [09], [10].
</content>

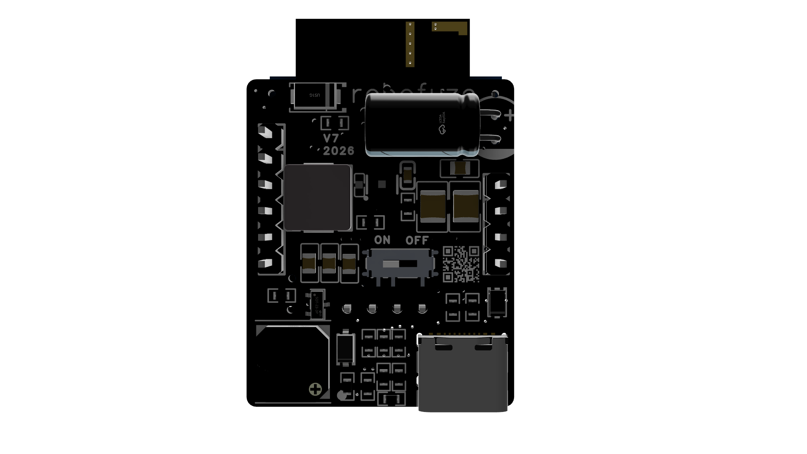
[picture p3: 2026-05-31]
.readme_images/3D_PCB1_2026-05-21 v42.png

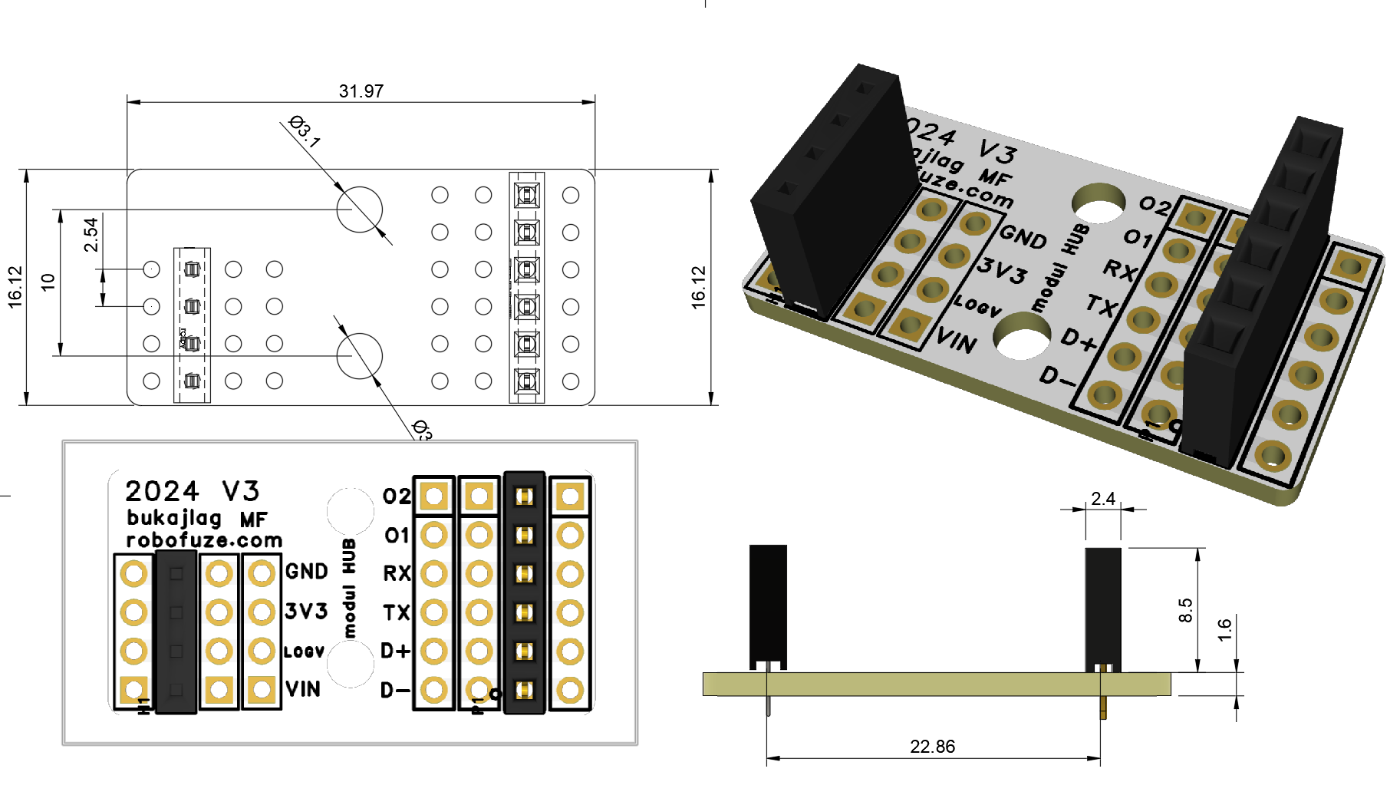
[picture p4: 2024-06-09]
.readme_images/hub_image.png

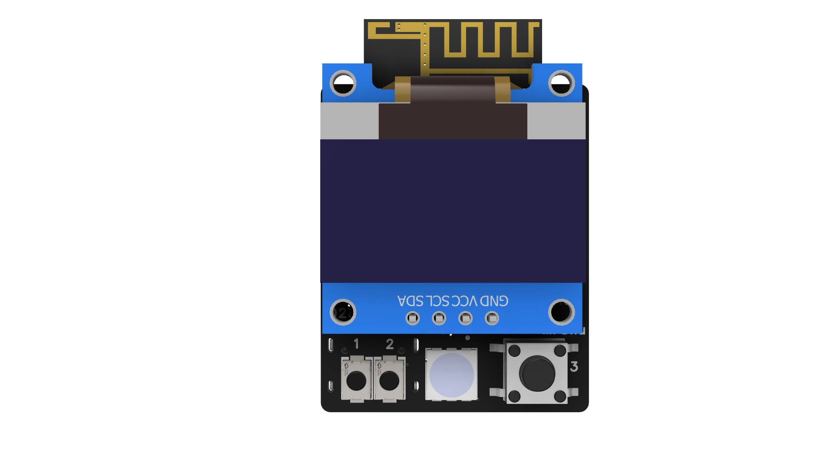
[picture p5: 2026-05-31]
.readme_images/3D_PCB1_2026-05-21 v4.png

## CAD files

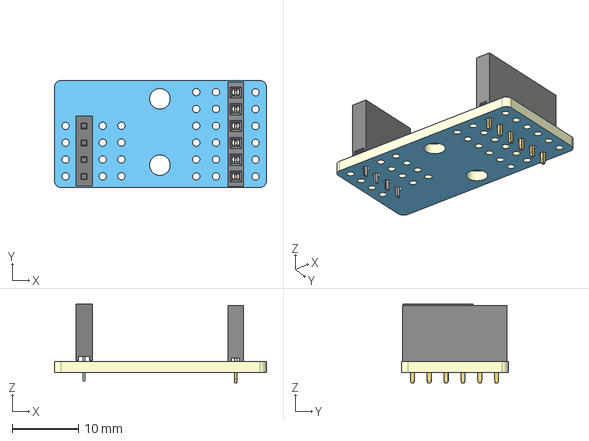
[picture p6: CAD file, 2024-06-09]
3d_model/hub_board.step
32.0 x 16.1 x 11.9 mm

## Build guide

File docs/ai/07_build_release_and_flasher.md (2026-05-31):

# 07 — Build, Release, and Flashing

## Build system overview

The project is an **ESP-IDF** application that pulls in **Arduino as an IDF component**
(`espressif/arduino-esp32`). The Arduino `.ino` also exists for local Arduino-IDE use, but
the **CI/release build uses the ESP-IDF path** (`main/app_main.cpp`).

### Target & toolchain

| Item | Value | Source |
|---|---|---|
| Chip | `esp32c5` | `CMakeLists.txt` (`set(IDF_TARGET "esp32c5")`), `sdkconfig.defaults` |
| ESP-IDF version | **v5.5.4** | `.github/workflows/firmware-release.yml` |
| Arduino component | `espressif/arduino-esp32` `^3.3.0` | `main/idf_component.yml` |
| BLE stack | **NimBLE** peripheral, GATT server | `sdkconfig.defaults` |
| FreeRTOS tick | 1000 Hz | `sdkconfig.defaults` (`CONFIG_FREERTOS_HZ=1000`) |
| Autostart Arduino | **off** (`CONFIG_AUTOSTART_ARDUINO=n`) — `app_main` calls `initArduino()` manually | `sdkconfig.defaults` |
| Flash | **8 MB**, mode `dio`, freq `80m` | `sdkconfig.defaults` (`CONFIG_ESPTOOLPY_FLASHSIZE_8MB`), `build/flasher_args.json` |

### ESP-IDF component layout

`main/CMakeLists.txt` registers everything as the single `main` component:
- App sources: `app_main.cpp` + `../ble.cpp`, `../ble_processing.cpp`, `../display.cpp`,
  `../functions.cpp`, `../state_machine.cpp`.
- Vendored libs compiled in: ThingPulse OLED (`OLEDDisplay*.cpp`), `QRcodeDisplay`
  (`frame-v1..v10.c`, `qrcodedisplay.cpp`, `qrencode.c`), `QRcodeOled` (`qrcodeoled.cpp`).
- `REQUIRES espressif__arduino-esp32`.
- `-Wno-error=overloaded-virtual` to tolerate the Arduino BLE class hierarchy warnings.

### Local build commands

```sh
cd firmware/RCj_comm_module
idf.py set-target esp32c5     # target is already pinned in CMakeLists/sdkconfig.defaults
idf.py build
# flash over USB-C:
idf.py -p <PORT> flash monitor
```

### Release vs debug build flavors

`idf.py build` uses `sdkconfig.defaults` (the **release** flavor): all bootloader/ESP-IDF/
Arduino-HAL logs are OFF and the console is on UART0, so the UART line carries only the
`PLAY`/`STOP` status output for robots that read serial. **CI always builds this flavor.**

For development with logs over the USB-C port, layer the **debug** overlay:

```sh
idf.py -D SDKCONFIG_DEFAULTS="sdkconfig.defaults;sdkconfig.debug" build flash monitor
```

`sdkconfig.debug` re-enables Info logging and routes the IDF console to USB-Serial-JTAG, so
logs appear over USB-C while UART0 stays clean. (Delete the generated `sdkconfig` when
switching flavors so the new defaults take effect.) See
[02_firmware_architecture.md](02_firmware_architecture.md#build-flavors-release-uart-clean-vs-debug-usb-verbose).

Arduino-IDE alternative: open `RCj_comm_module.ino`, select an ESP32-C5 board, ensure the
bundled `libraries/` are on the path. (Less tested; CI does not use this.)

> **Build environment in this checkout:** ESP-IDF was **not available** when this doc was
> written (`IDF_PATH` empty, no `idf.py` on `PATH`). A previous build output exists under
> `firmware/RCj_comm_module/build/` and `managed_components/` (both gitignored). A fresh
> `idf.py build` could not be executed/verified here — see [verification](#verification-status).

## GitHub Actions release flow

File: `.github/workflows/firmware-release.yml`. Triggered on **tag push** matching
`fw-*` or `v*`.

```
push tag (fw-* | v*)
   │
   ├─ job: build  (ubuntu-latest)
   │   1. checkout (submodules: recursive)
   │   2. espressif/esp-idf-ci-action@v1  (esp_idf_version v5.5.4, target esp32c5)  → idf build
   │   3. esp-idf-ci-action  → python ../../tools/prepare_firmware_release.py
   │         --project-dir . --web-src ../../web/flasher --output-dir ../../dist
   │         --version ${{ github.ref_name }}
   │   4. upload-artifact "firmware-release" (dist/)
   │   5. configure-pages + upload-pages-artifact (dist/)
   │
   ├─ job: release  (needs build)
   │     download artifact → gh release create/upload (clobber if exists)
   │        files: dist/firmware/*, dist/manifest.json, dist/version.json, dist/release-notes.md
   │
   └─ job: deploy-pages  (needs build)
         actions/deploy-pages@v4  → publishes dist/ (web flasher + firmware) to GitHub Pages
```

### Tag naming

- `fw-vX.YZ` (e.g. `fw-v0.95`, `fw-v0.96`) — current convention; also accepts `v*`.
- `github.ref_name` becomes the `--version` and the file-name version (`safe_name()`
  sanitizes it). **Keep `definitions.h` `FW_VERSION_MAJOR/MINOR` in sync with the tag**
  (`definitions.h` is currently 0/97; latest released tag is `fw-v0.96`, so a `fw-v0.97`
  tag should accompany the next release).

## `tools/prepare_firmware_release.py`

Run inside the IDF env after `idf.py build`. Steps:

1. Reads `build/flasher_args.json` (chip, flash settings, flash files + offsets).
2. Copies the static flasher site (`web/flasher/`) into `dist/`, plus the V7 board render
   `.readme_images/3D_PCB1_2026-05-21 v41.png` → `dist/assets/module.png` (referenced by
   `web/flasher/index.html`).
3. Copies build artifacts into `dist/firmware/` with versioned names:
   - `rcj_comm_module-<ver>.bin` (app)
   - `rcj_comm_module-<ver>-bootloader.bin`
   - `rcj_comm_module-<ver>-partition-table.bin`
   - `rcj_comm_module-<ver>-merged.bin` (via `esptool ... merge_bin`, single image)
4. Writes:
   - `manifest.json` — esptool-js/ESP-Web-Tools style; uses the **merged** image at offset
     `0x0`, `chipFamily` derived as `ESP32-C5`, `new_install_prompt_erase: true`.
   - `version.json` — version, chip, `chipFamily`, `releaseUrl`, commit SHA, per-file
     size+sha256.
   - `release-notes.md` — human-readable list of files.

> The web flasher consumes `manifest.json` + `version.json` + the merged `.bin`. The
> individual app/bootloader/partition bins are for `idf.py`/esptool users.

## Web flasher (`web/flasher/`)

Static site (`index.html`, `app.js`, `styles.css`, `.nojekyll`). Uses **esptool-js 0.6.0**
(from unpkg) and the browser **Web Serial API**.

| Constant (`app.js`) | Value |
|---|---|
| `CHIP_FAMILY` | `"ESP32-C5"` |
| `RESET_MODE` | `"usb_reset"` (USB-CDC bootloader entry) |
| `BAUD_RATE` | `115200` |

Flow:
1. On load, fetch `version.json` + `manifest.json`, display version/chip/size/sha.
2. On "Install firmware": `navigator.serial.requestPort()` → `Transport` → `ESPLoader`.
3. `loader.main("usb_reset")` enters the bootloader via USB; `assertExpectedChip()` checks
   the connected chip == `ESP32-C5`.
4. `writeFlash({ fileArray: [merged@0x0], eraseAll: true, compress: true, ... })` with
   progress reporting.
5. After flashing, `hardResetViaUsbSerial()` toggles **DTR/RTS** to reset the module
   (this is the logic refined in commits `51a724e` / `20db907`).

### Requirements / behavior

- **Desktop Chrome or Edge** required (Web Serial). The UI disables the button and shows
  "Web Serial unavailable" otherwise (`index.html` note + `app.js` guard).
- Connect the module over **USB-C** before starting. Flash is fully erased first
  (`eraseAll: true`, `new_install_prompt_erase: true`).
- The merged image is flashed at offset `0x0`.

## Source files vs generated artifacts

| Source (commit these) | Generated (do NOT commit) |
|---|---|
| `web/flasher/*`, `tools/prepare_firmware_release.py`, workflow yml, firmware sources | `dist/**`, `build/**`, `managed_components/**`, `manifest.json`, `version.json`, `release-notes.md`, merged/app/bootloader/partition `.bin` |

## Verification status

- **A full clean rebuild was run and verified (2026-05-31)** with ESP-IDF v5.5.4
  (`~/.espressif/v5.5.4`): `rm sdkconfig && idf.py fullclean && idf.py build` succeeded.
  The stale `sdkconfig` (pre-dating the release-config changes) had to be deleted so the new
  `sdkconfig.defaults` (log-NONE, 8 MB flash) would regenerate — the VSCode Espressif
  extension also reuses an existing `sdkconfig`, so delete it / "Full Clean" there too.
- `build/flasher_args.json` now reports `esp32c5`, **8 MB flash** (matching the chip's JEDEC
  read), `dio`/`80m`, bootloader@`0x2000`, partition-table@`0x8000`, app@`0x10000`. App
  image is ~0xcbb10 bytes (≈20% free in the 1 MB app partition).

## Source files reviewed

`.github/workflows/firmware-release.yml`, `tools/prepare_firmware_release.py`,
`web/flasher/{index.html,app.js}`, `CMakeLists.txt`, `main/CMakeLists.txt`,
`main/idf_component.yml`, `sdkconfig.defaults`, `build/flasher_args.json`, README.

## Open questions

- Is the bundled `libraries/` copy authoritative, or should those become managed components?
- Are submodules actually used? (workflow checks out `submodules: recursive`, but no
  `.gitmodules` was observed — verify.)
</content>

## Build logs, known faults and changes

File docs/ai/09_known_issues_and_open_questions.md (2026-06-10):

# 09 — Known Issues and Open Questions

Consolidated risks, contradictions, TODOs, and unknowns. Resolve the **blockers** before
implementing any new-hardware feature.

## Public docs vs code

The public `README.md` was **rewritten on 2026-05-31** to match the V7/2026 (C5) hardware, so
the old contradictions below are now **reconciled** — kept here as history.

| Topic | Old README / 2024 PDF said | Reality (now reflected in README) |
|---|---|---|
| MCU | (implied 2024 ESP32-C6 hardware) | ESP32-**C5** (`master`); C6 lives on `legacy/esp32-c6` |
| Robot-to-robot comms | "Use RX, TX for UART… LOGV… A0/A1 channels (00/01/10/11)" | **No robot-to-robot protocol in firmware** (planned); no LOGV/A0/A1 on V7. README now says so. |
| Start/stop readout | OUT pins only | OUT pins **or** `PLAY`/`STOP` on UART0 |
| Board version | "RCJ Soccer SuperTeams 2024", `modul_v3` | New board silk **"V7 2026"** ("robofuze"); README title de-yeared |
| Schematic | `pcb_schematic/SCH.pdf` (2024) | V7 schematic `SCH_Schematic1_2026-05-31.pdf` present; old 2024 files removed |

## TODO / suspicious comments in code

- `state_machine.cpp:88` — `stm_set_timer(660000); //DOTO why ist here this? WTF`.
  An 11-minute timer set at init with no clear purpose. **Do not remove blindly.**
- `ble.cpp` — `//stm_set_state(STM_PLAY);` commented out in `onConnect` (connect no longer
  auto-plays — intentional).
- `update_output_satet()` — typo in function name (`satet` → `state`); cosmetic.
- Numerous commented-out `Serial.println` debug lines (`ble.cpp`, `ble_processing.cpp`,
  `functions.cpp`).

## Recently resolved

- ✅ **BLE supervision timeout lowered 20 s → 3 s** (`BLE_CONN_TIMEOUT` 2000 → **300**) in
  **fw v0.97** (2026-05-31). Fixed two effects of the old 20 s value: (1) phone reconnect
  took up to ~20 s after link loss; (2) safety — on a *silent* link loss the robot could keep
  **playing for up to ~20 s** before the module's `onDisconnect` fail-safed to STOP. The 20 s
  value had been intentional anti-flap; the C5 supercap reduces that need.
  **Still to do:** (a) validate 3 s on real hardware doesn't cause spurious disconnects during
  normal play; (b) cherry-pick to the `legacy/esp32-c6` branch before the first legacy release.
  See [03_ble_protocol.md](03_ble_protocol.md), [11_legacy_c6_firmware.md](11_legacy_c6_firmware.md).

## Functional issues / sharp edges

1. **Two entry points must stay in sync** (`RCj_comm_module.ino` vs `main/app_main.cpp`).
   Editing one and not the other silently diverges the Arduino-IDE and CI builds.
2. **Shared button pin** — `BUTTON_GPIO` (10) drives both disconnect long-press and penalty
   double-press; redefining button roles affects both paths.
3. **Render gating** — `STM_DISCONNECTED` only redraws on state change, so `SET_SCORE`/
   `SET_NAME` updates received while idle don't show until a state change.
4. **No timer auto-expiry transition** — penalty/halftime countdown reaching 0 does not
   change state; the app must send the next command.
5. **Unprotected shared state** — `current_state`/`state_changed` are written from both the
   loop and the BLE host context without locks (benign so far, but a latent race).
6. **Buttons set as `INPUT`** (not `INPUT_PULLUP`) — relies on board/external pull-ups;
   verify against the schematic to avoid floating inputs.
7. **No BLE security** — open GATT server; any central can send commands. Acceptable for the
   use case but worth noting.
8. **`FW_VERSION` macro** — `FW_VERSION = MAJOR*0xFF + MINOR` (note `*0xFF`, not `*100` or
   `<<8`); the over-BLE reply sends `MAJOR` and `MINOR` separately, so this combined macro's
   only consumer/intent is unclear.

## Schematic details — NOW RESOLVED

The V7/2026 schematic (`pcb_schematic/SCH_Schematic1_2026-05-31.pdf`) and the hardware
reference (`docs/ai/ESP32C5_RCJ_modul_hardware_reference.md`) are now in the repo. The
previously-blocking unknowns are resolved (see [05_hardware_mapping.md](05_hardware_mapping.md)):

- **Firmware pins match the V7 board** for all implemented peripherals (I2C IO2/IO3,
  OUT1=IO9, OUT2=IO8, BUTTON=IO10/B1/SW5, BUTTON2=IO7/B2/SW1). The earlier "firmware pin map
  is wrong for V7" concern came from a since-corrected draft of the reference doc and is
  **not** an issue.
- **RGB LED**: discrete common-cathode, active-high, R=IO27 / G=IO24 / B=IO23 (470 Ω each),
  PWM-capable. ⚠️ **Red/Green are physically swapped (confirmed bug, 2026-06-02):** the LED1
  footprint is wired R,G,B but the real `TC5050RGBF08` part is **G,R,B**, so **IO27 lights
  green and IO24 lights red** (blue is correct). Firmware must drive IO24 for red / IO27 for
  green; the proper fix is correcting the footprint in a future board revision.
- **Buzzer**: passive 2.7 kHz via NPN Q1; GPIO **IO26 (pin 27)** — confirmed by maintainer.
- **Third button** B3 = IO6 (SW2), active-low w/ 10 kΩ pull-up. Intended function still TBD.
- **Button pulls**: external 10 kΩ (R4/R5/R6), so `INPUT` (no internal pull-up) is fine.
- **UART**: UART0 (RX0/TX0, flashing/primary) and UART1 (RX1=IO4, TX1=IO5) on U3 header.
- **USB**: native USB-CDC on IO13/IO14 (the flashing/reset path) — do not reassign.

Residual low-risk verifications (do not block re-pinning) are listed in
[05_hardware_mapping.md](05_hardware_mapping.md#residual-items-to-verify-low-risk-do-not-block-firmware-re-pinning)
(OLED pull-ups, RGB polarity on bring-up — note the **confirmed R/G footprint swap** above).

## Open product/process questions for the maintainer

1. Must BLE protocol stay **byte-compatible** with the currently shipped app? (Enum ordinals
   are the wire IDs — any reorder breaks it.)
2. Must **old-module (C6) compatibility** be preserved, or is C5 now the only target? Can the
   commented C6 pin block be removed? — **Decided:** C5-only on `master`; C6 lives on a
   `legacy/esp32-c6` branch. See [11_legacy_c6_firmware.md](11_legacy_c6_firmware.md).
3. Is the **UART robot-to-robot** feature still required/planned, or fully deprecated?
4. Supercapacitor: pure hardware ride-through, or should firmware **detect/announce** a power
   dip (LED/buzzer/BLE notification, safe-state)?
5. Desired **RGB LED** and **buzzer** semantics per state/event (the tables in
   [06](06_display_and_user_feedback.md) are guesses). Pins are now known (RGB R/G/B =
   IO27/IO24/IO23; buzzer = IO26).
6. Intended role of the **third button** B3 = **IO6 / SW2** (menu? channel? manual play/stop?).
7. Purpose of the **`660000 ms`** init timer — keep, fix, or remove?
8. Should the `.ino` entry point be retired in favor of the IDF `main/` path?

## Build/CI notes

- ESP-IDF was not available in this checkout; a fresh build was not verified here.
- The workflow checks out `submodules: recursive`, but **no `.gitmodules` exists** — the
  recursive flag is currently a no-op. Confirm whether submodules are planned.

## Source files reviewed

All firmware sources, workflow, flasher, README, render images, git history.
</content>

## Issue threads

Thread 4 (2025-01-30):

Score not cleared after the game

SchmidtBytes, 2025-01-30:
Hi,

When a game is finished and another is started with the restart button the old score still shows on the communication modules.
The app clears fine and the score is properly updated when changing it in the app.

Final score after the game is showing correct if it was not updated during the game.

br,
Schmidtbytes

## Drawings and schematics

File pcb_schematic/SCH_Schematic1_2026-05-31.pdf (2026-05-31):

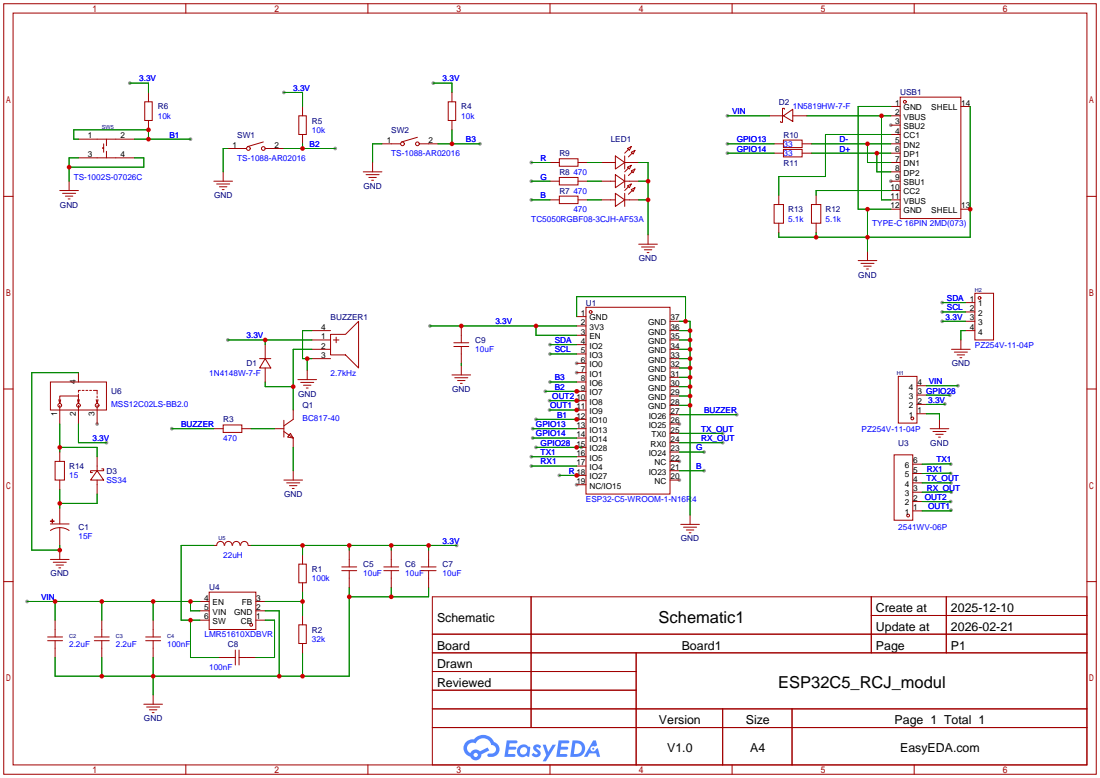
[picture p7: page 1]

Schematic | Schematic1 | Create at | 2025-12-10

Update at | 2026-02-21

Board | Board1 | Page | P1
Drawn | | ESP32C5_RCJ_modul
Reviewed

Version | Size | Page 1 Total 1
V1.0 | A4 | EasyEDA.com

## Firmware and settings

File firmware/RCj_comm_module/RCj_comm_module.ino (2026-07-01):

#include <Arduino.h>
#include "definitions.h"
#include "ble.h"
#include "functions.h"
#include "state_machine.h"
#include "ble_processing.h"
#include "display.h"
#include "serial_status.h"

void setup() {
    Serial.begin(UART_SPEED);
    serial_status_init();
    
    // Init display
    display_init();

    module_init_gpios();

    stm_init();   

    ble_start_server();

}

void loop() {

    ble_msg_processing();

    stm_update();

    check_disconnect_button();

    check_penalty_button();

}

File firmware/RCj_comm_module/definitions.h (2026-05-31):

#ifndef DEFINITIONS_H
#define DEFINITIONS_H

#define FW_VERSION_MAJOR    0
#define FW_VERSION_MINOR    97
#define FW_VERSION          (FW_VERSION_MAJOR*0xFF + FW_VERSION_MINOR)

#define DEFAULT_INDICATOR   "--"

// UART
#define UART_SPEED      115200

// BLE
#define BLE_NAME            "RCJs-m_" + BLE_MAC_to_string()
#define BLE_DATA_MAX_LENGTH 10
#define BLE_QUEUE_MAX_SIZE  16
#define BLE_CONN_INTERVAL_MIN 12     // 15 ms, units are 1.25 ms
#define BLE_CONN_INTERVAL_MAX 24     // 30 ms, units are 1.25 ms
#define BLE_CONN_LATENCY      0
#define BLE_CONN_TIMEOUT      300    // 3 s, units are 10 ms

// Disconnect button hold time
#define DISCONNECT_HOLD_TIME    5000

/*** GPIOs (ESP32-C5) ***/
// The legacy ESP32-C6 (2024 board) pin map lives on the `legacy/esp32-c6` branch.
// I2C
#define I2C_SDA_GPIO    2
#define I2C_SCL_GPIO    3

// Button
#define BUTTON_GPIO     10
#define BUTTON2_GPIO     7

// Status pins
#define OUTPUT1_GPIO    9
#define OUTPUT2_GPIO    8

#endif // DEFINITIONS_H

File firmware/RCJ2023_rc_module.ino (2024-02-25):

#include <BLEDevice.h>
#include <BLEServer.h>
#include <BLEUtils.h>
#include <BLE2902.h>

#define LED_RED   0
#define LED_GREEN 10
#define LED_BLUE  1
#define LED_IR    2
#define BUTTON    3
#define I2C_SDA   6
#define I2C_SCL   7
#define DIG_OUT_1 5
#define DIG_OUT_2 4


BLEServer *pServer = NULL;
BLECharacteristic * pTxCharacteristic;
BLECharacteristic * pRxCharacteristic;
bool deviceConnected = false;
bool oldDeviceConnected = false;
std::string BLErxValue;
uint8_t txValue = 0;

bool robot_play = false;
bool state_changed = false;

// See the following for generating UUIDs:
// https://www.uuidgenerator.net/

#define SERVICE_UUID           "6E400001-B5A3-F393-E0A9-E50E24DCCA9E" // UART service UUID
#define CHARACTERISTIC_UUID_RX "6E400002-B5A3-F393-E0A9-E50E24DCCA9E"
#define CHARACTERISTIC_UUID_TX "6E400003-B5A3-F393-E0A9-E50E24DCCA9E"


class MyServerCallbacks: public BLEServerCallbacks {
    void onConnect(BLEServer* pServer) {
      deviceConnected = true;
    };

    void onDisconnect(BLEServer* pServer) {
      deviceConnected = false;
    }
};

class MyCallbacks: public BLECharacteristicCallbacks {
    void onWrite(BLECharacteristic *pCharacteristic) {
      BLErxValue = pCharacteristic->getValue();

      if (BLErxValue.length() > 0) {
        //        Serial.println("*********");
        //        Serial.print("Received Value: ");
        //        for (int i = 0; i < BLErxValue.length(); i++)
        //          Serial.print(BLErxValue[i]);
        //
        //        Serial.println();
        //        Serial.println("*********");

        switch (BLErxValue[0]) {
          case 'G':
            if (!robot_play) {
              state_changed = true;
            }
            robot_play = true;
            break;
          case 'S':
            if (robot_play) {
              state_changed = true;
            }
            robot_play = false;
            break;
        }
      }
    }
};


void setup() {
  Serial.begin(9600);

  // Init GPIOs
  pinMode(LED_RED, OUTPUT);
  pinMode(LED_GREEN, OUTPUT);
  pinMode(LED_BLUE, OUTPUT);
  pinMode(LED_IR, OUTPUT);
  pinMode(DIG_OUT_1, OUTPUT);
  pinMode(DIG_OUT_2, OUTPUT);
  pinMode(BUTTON, INPUT);

  digitalWrite(LED_RED, LOW);
  digitalWrite(LED_GREEN, LOW);
  digitalWrite(LED_BLUE, HIGH);
  digitalWrite(LED_IR, LOW);
  digitalWrite(DIG_OUT_1, HIGH);
  digitalWrite(DIG_OUT_2, HIGH);

  Serial.println("S");


  // Create the BLE Device
  BLEDevice::init("RCJ-rc");

  // Create the BLE Server
  pServer = BLEDevice::createServer();
  pServer->setCallbacks(new MyServerCallbacks());

  // Create the BLE Service
  BLEService *pService = pServer->createService(SERVICE_UUID);

  // Create a BLE Characteristic
  pTxCharacteristic = pService->createCharacteristic(
                        CHARACTERISTIC_UUID_TX,
                        BLECharacteristic::PROPERTY_NOTIFY
                      );

  pTxCharacteristic->addDescriptor(new BLE2902());

  pRxCharacteristic = pService->createCharacteristic(
                        CHARACTERISTIC_UUID_RX,
                        BLECharacteristic::PROPERTY_WRITE
                      );

  pRxCharacteristic->setCallbacks(new MyCallbacks());

  // Start the service
  pService->start();

  // Start advertising
  pServer->getAdvertising()->start();
  //Serial.println("Waiting a client connection to notify...");
}

void loop() {

  // disconnecting
  if (!deviceConnected && oldDeviceConnected) {
    delay(500); // give the bluetooth stack the chance to get things ready
    pServer->startAdvertising(); // restart advertising
    //Serial.println("start advertising");
    oldDeviceConnected = deviceConnected;
    digitalWrite(LED_RED, LOW);
    digitalWrite(LED_GREEN, LOW);
    digitalWrite(LED_BLUE, HIGH);
  }
  // connecting
  if (deviceConnected && !oldDeviceConnected) {
    // do stuff here on connecting
    oldDeviceConnected = deviceConnected;
    state_changed = true;
  }

  if (state_changed) {
    state_changed = false;
    if (robot_play) {
      Serial.println("G");
      digitalWrite(LED_RED, LOW);
      digitalWrite(LED_GREEN, HIGH);
      digitalWrite(LED_BLUE, LOW);
      digitalWrite(DIG_OUT_1, HIGH);
      digitalWrite(DIG_OUT_2, HIGH);
    } else {
      Serial.println("S");
      digitalWrite(LED_RED, HIGH);
      digitalWrite(LED_GREEN, LOW);
      digitalWrite(LED_BLUE, LOW);
      digitalWrite(DIG_OUT_1, LOW);
      digitalWrite(DIG_OUT_2, LOW);
    }
  }


}

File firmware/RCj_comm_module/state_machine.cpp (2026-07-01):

#include <ctime>
#include "esp32-hal.h"
#include <sys/_stdint.h>
#include "WString.h"
#include <Arduino.h>
#include "HardwareSerial.h"
#include "freertos/projdefs.h"
#include <stdint.h>
#include "esp_err.h"

#include "definitions.h"
#include "display.h"
#include "serial_status.h"
#include "state_machine.h"

static stm_states current_state = STM_INIT;
static bool state_changed = false;
static bool robot_play = false;
static uint32_t timer_stop = 0;

static uint16_t get_remaining_time() {
    uint32_t current_time = millis();
    if (current_time < timer_stop) {
        return (timer_stop - current_time) / 1000;
    }
    return 0;
}

static void update_output_satet() {
    if (robot_play) {
        digitalWrite(OUTPUT1_GPIO, HIGH);
        digitalWrite(OUTPUT2_GPIO, HIGH);
        serial_status_println("PLAY");
    } else {
        digitalWrite(OUTPUT1_GPIO, LOW);
        digitalWrite(OUTPUT2_GPIO, LOW);
        serial_status_println("STOP");
    }
}


// States
static void state_init() {
    display_screen_init();
    delay(2000);
    stm_set_state(STM_DISCONNECTED);
}

static void state_disconnected() {
    robot_play = false;          // fail-safe: stop the robot when the phone link drops
    display_screen_wait_for_connection();
}

static void state_play() {
    robot_play = true;
    display_screen_play();
}

static void state_stop() {
    robot_play = false;
    display_screen_stop();
}

static void state_damage() {
    robot_play = false;
    display_screen_damage(get_remaining_time());

}

static void state_half_break() {
    robot_play = false;
    display_screen_half_break(get_remaining_time());
}

static void state_game_over() {
    robot_play = false;
    display_screen_game_over();
}



// Public functions
int8_t stm_set_timer(uint32_t miliseconds) {
    timer_stop = millis() + miliseconds;

    return ESP_OK;
}

int8_t stm_init() {
    stm_set_timer(660000); //DOTO why ist here this? WTF

    return ESP_OK;
}

void stm_set_state(stm_states state) {
    current_state = state;
    state_changed = true;
}

stm_states stm_get_state() {
    return current_state;
}

int8_t stm_update() {
    bool change_noted = false;

    if (state_changed) change_noted = true;

    switch (current_state) {
        case STM_INIT:
            state_init();
            break;
        case STM_DISCONNECTED:
            if (state_changed) {
                state_disconnected();
            }
            break;
        case STM_PLAY:
            state_play();
            break;
        case STM_STOP:
            state_stop();
            break;
        case STM_DAMAGE:
            state_damage();
            break; 
        case STM_HALF_TIME:
            state_half_break();
            break;
        case STM_GAME_OVER:
            state_game_over();
            break;             
        default:
            // statements
            break;
    }

    if (state_changed) {
        update_output_satet();
    }

    if (change_noted) state_changed = false;

    return ESP_OK;
}

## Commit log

2024-02-25 Initial commit with information as distributed to RCJ 2023 teams
    [RCJ_com_v2.brd, RCJ_com_v2.sch, RCJ_com_v2_top_bom.csv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]
2024-06-09 How to mount it
    [hub_board.step]
2026-03-12 add support for ESP32-C5
2026-05-17 Migrate firmware to ESP-IDF Arduino component
2026-05-18 fix: make release workflow repo explicit
    Previously the release job used gh without a checkout, which left the CLI
    unable to infer the repository. This commit passes the repository from the
    Actions context so artifact publishing works in checkout-free jobs.
    - Set `GH_REPO` for the firmware release publishing step
    - Keep the existing artifact contents and tag-triggered flow unchanged
2026-05-19 Fix ESP32-C5 web flasher reset
2026-05-19 Improve ESP32-C5 flasher reset
2026-05-31 Firmware v0.97 (C5): faster BLE timeout, clean release UART, 8 MB flash, AI docs
    - BLE_CONN_TIMEOUT 2000 (20 s) -> 300 (3 s): faster reconnect and faster
    fail-safe STOP after a silent link loss.
    - sdkconfig.defaults: silence bootloader/IDF/Arduino-HAL logs and pin the
    console to UART0 so the robot-facing UART carries only PLAY/STOP. Set flash
    size to 8 MB to match the chip's JEDEC ID (was defaulting to 2 MB).
    - sdkconfig.debug: optional overlay for USB-Serial-JTAG logging during dev.
    - Add docs/ai/ agent documentation set + ESP32-C5 hardware reference, the V7
    schematic PDF, V7 render images, and the previous-session AI_HANDOFF.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
    [definitions.h]
2026-05-31 Remove redundant commented C6 pin block from definitions.h
    master is C5-only now; the ESP32-C6 pin map lives on the legacy/esp32-c6
    branch. Left a one-line pointer to that branch.
2026-05-31 README: add Legacy 2024 (ESP32-C6) modules section
    Document that old C6 boards are supported via the legacy/esp32-c6 branch and
    legacy-c6-* GitHub Releases, with native-USB flashing steps (and a note on the
    fiddlier level-shifted UART path).
2026-05-31 Update repo + README for V7 (ESP32-C5) hardware; remove old 2024 design files
    README rewritten for the current V7/2026 board:
    - Drop "2024" from the title; describe ESP32-C5 HW (USB-C, RGB LED, buzzer,
    3 buttons, supercap backup, soft power switch).
    - Power input 4.5-50 V (LMR51610 buck; capped at the 50 V rules limit) or USB-C.
    - Start/stop is readable from OUT pins or as PLAY/STOP on UART0.
    - Remove the obsolete robot-to-robot UART/LOGV/A0-A1 section (not on V7; the
    protocol is planned for a future release).
    - Add web flasher link, Google Play link, and the separate app repo link.
    - Hero image -> new V7 render (3D_PCB1_2026-05-21 v41.png).
    Remove old 2024/v3 (C6) design artifacts from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
    [1_P1.schdoc.schdoc, PCB1.pcbdoc, PickAndPlace_modul_2024-04-05.xlsx]
2026-06-03 README: restructure for V7 module; add quick-connection flyer
    - Reorder so the mobile app + web flasher come right after the intro
    - Add a top note pointing older 2024 (ESP32-C6) users to the legacy section
    - Fix power wording: short ~0.5 A @ 3.3 V startup demand (not 500 mA at all times)
    - Start/stop methods as a table (OUT pins vs UART0 PLAY/STOP)
    - Center the hero render; turn the hub photo into a link
    - Add printable A5 quick-connection guide flyer at the end
2026-06-10 docs: note RGB LED Red/Green footprint swap (IO27=green, IO24=red)
    The LED1 footprint in the V7 schematic is wired R,G,B, but the real
    TC5050RGBF08 part is G,R,B, so the Red/Green pads are reversed on the PCB.
    On the real board IO27 lights green and IO24 lights red (blue is correct).
    Confirmed on hardware 2026-06-02 while testing PR #8.
    Annotated all six docs that describe the LED so future firmware drives
    IO24 for red / IO27 for green, or the footprint gets corrected in a board
    revision.
2026-07-01 fix: stop robot on BLE disconnect (fail-safe) — closes #10
    STM_DISCONNECTED only refreshed the display and left robot_play=true, so
    update_output_satet() re-asserted OUTPUT1/2 HIGH after a link loss and the
    robot kept playing until power-cycle/reconnect.
    Add state_disconnected() which forces robot_play=false on entry (mirroring
    state_stop), so the play outputs go LOW within the 3 s BLE supervision
    window. Replaces the now-redundant state_wait_connecting() helper.
    [state_machine.cpp]
